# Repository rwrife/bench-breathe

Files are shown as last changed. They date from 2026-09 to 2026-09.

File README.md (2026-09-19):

# Bench Breathe

USB-powered ESP32-C3 workshop air-quality logger that tracks PM2.5 and VOC trends locally to help makers improve ventilation habits without cloud accounts.

## Overview

Bench Breathe is a low-voltage, local-first open-hardware project for hobby workshops and desk labs. It samples particulate and VOC indicators with temperature/humidity context, stores bounded trend history locally, and provides a local companion dashboard for setup, quality states, event notes, and explicit export.

**Bench Breathe is a non-certified advisory trend logger.** It does not determine whether air is safe and is not a medical, emergency, life-safety, or occupational-exposure instrument.

## Intended users and use cases

- Electronics hobbyists comparing trends during soldering or rework.
- 3D-printing users comparing baseline and active-print periods.
- Home workshop users recording manual actions such as opening a window or enabling an independently controlled extractor.
- Makers exporting their own local CSV/JSON data for troubleshooting and analysis.

## MVP workflow

1. Power the device from a reputable 5 V USB SELV source.
2. Connect from a phone/desktop browser on the local network or use USB serial fallback.
3. Complete time-bounded setup and baseline/warm-up prompts.
4. Record a work session and optional ventilation event labels.
5. Review local trends, freshness, quality states, and data gaps.
6. Export or delete local data through an explicit user action.

## Frozen MVP baseline

The normative baseline is in [`hardware/requirements.md`](hardware/requirements.md), with subsystem ownership, dependencies, evidence gates, and the risk register in [`PLAN.md`](PLAN.md).

Key constraints:

- USB 5 V SELV only; <=250 mA steady-state target and <=500 mA peak.
- PM2.5, VOC proxy/index, temperature, and humidity trend channels.
- Default 2 s acquisition, bounded local retention, and deterministic rollover.
- Local HTTP/JSON app interface with USB serial setup/recovery/export fallback.
- Offline sampling without mandatory internet, cloud account, or outbound telemetry.
- Editable KiCad hardware sources and schematic-owned Manufacturer/MPN BOM data.
- Advisory trend language only; static, simulation, bench, and field evidence remain distinct.

## Explicit non-goals and safety limits

- **No mains wiring or control.** No relays, fan switching, actuators, machinery control, or safety interlocks.
- **No hazardous-voltage or USB-PD operation.** The project is nominal 5 V USB SELV only.
- **No medical, emergency, fire/smoke/gas-alarm, life-safety, or occupational-limit function.**
- **No certified accuracy or safe/unsafe determination.** Placement, warm-up, drift, contamination, airflow, and faults can produce misleading data.
- **No mandatory cloud service or internet access.**
- Indoor, dry, non-condensing hobby-workshop use only; not for outdoor, explosive, or industrial-process environments.

Users must follow tool/material manufacturer guidance and appropriate ventilation and PPE practice independently of this device.

## Architecture at a glance

- **Hardware:** USB input/protection/regulation, ESP32-C3, PM/VOC/temp-humidity interfaces, status/input, debug/test access, PCB, and enclosure interface.
- **Firmware:** deterministic acquisition, validity states, bounded retention, atomic configuration, versioned local API, and serial recovery.
- **Companion web app:** setup, status/history, event notes, configuration, explicit export/delete, and accessible advisory messaging.
- **Shared protocol:** [`docs/protocol.md`](docs/protocol.md) is finalized contract v1 (HTTP + USB-serial shapes, units, limits, errors, authorization). The firmware baseline still streams the v0-compatible serial line; adoption is tracked in `docs/release-checklist.md` (T-1).

The device remains authoritative for sensor state, timestamps, configuration limits, and retained records. The app presents that contract and must not turn null/invalid values into apparently valid measurements. For the MVP, compiled app assets are served by the device for offline same-origin use. A physical, time-bounded setup action issues the per-device local credential; this reduces casual LAN access but does not make cleartext HTTP confidential or safe for internet exposure.

## Source tree

- `hardware/requirements.md` — normative MVP requirements and safety boundaries
- `hardware/kicad/bench-breathe.kicad_pro` — editable KiCad project container
- `hardware/kicad/bench-breathe.kicad_sch` — editable A0 electrical schematic and schematic-owned BOM-property source
- `hardware/kicad/bench-breathe.kicad_pcb` — planned editable PCB
- `hardware/component-selection.md` — exact M2 parts, manufacturer-datasheet checks, static power budget, and dated availability snapshot
- `firmware/` — device firmware and verification
- `app/` — local companion web app
- `docs/protocol.md` — device/app contract (v1)
- `docs/bring-up.md` — integration bring-up procedure, wiring/pinouts, calibration, troubleshooting matrix, and evidence ledger
- `docs/release-checklist.md` — fabrication/release artifact gates and open tracked items
- `bom/bom.csv` — generated stuffed-BOM export from schematic properties (regenerate with `python3 bom/export_bom.py`, gate with `python3 bom/verify_bom.py`)
- `bom/README.md` — BOM workflow, sourcing/pricing policy, and file roles
- `bom/non-schematic-items.csv` — enclosure, cables, fasteners, adapter, power supply, and PCB fab with explicit planning status

The current `bom/preliminary-bom.csv` is the issue-#2 planning list reconciled against the schematic (`Schematic_Refs`/`Reconciliation` columns). It is not a fabrication-ready BOM; `bom/bom.csv` is the export artifact.

## Project status

| Milestone | Status |
|---|---|
| M1 — Requirements, architecture, safety, and risk baseline | Baseline documented |
| M2 — Datasheet-backed component selection | Static selection complete; physical validation not started |
| M3 — Editable KiCad schematic and ERC | Complete: clean KiCad 9 ERC plus static validation and PDF review export |
| M4 — Schematic-source BOM export | Complete: `bom/bom.csv` generated from schematic properties with reproducibility + no-fabricated-price gate (`bom/verify_bom.py`) |
| M5 — PCB layout and DRC | A0 evidence board complete: 0 DRC violations with 15 documented unrouted stubs — **not fab release** (see `hardware/pcb-notes.md` §Residuals and `docs/release-checklist.md`) |
| M6 — Firmware baseline | Baseline implemented + natively verified (19 unit tests, pinned device build). Bench flash/flash-recovery and power gating on hardware not performed |
| M7 — Companion app baseline | App MVP + contract v1 complete; 13/13 contract tests against the dev simulator only — never run against a real device |
| M8 — Integration and bench bring-up | Bring-up procedure, wiring/pinouts, and troubleshooting published (`docs/bring-up.md`); all bench steps unexecuted — no prototype exists |
| M9 — Mature fabrication/release bundle | Gate checklist published (`docs/release-checklist.md`); fab artifacts blocked on A1 stub closure |

The editable A0 schematic and its static ERC/analyzer evidence are complete,
as is the A0 evidence PCB (0 DRC violations, 15 documented unrouted stubs —
not fab release), the natively verified firmware baseline, and the
contract-tested companion app (simulator-evidence only). PCB fab export,
simulation, firmware/app builds on hardware, assembly, bench measurement,
field results, and certification are not claimed. See
`docs/bring-up.md` (bench procedure and evidence ledger) and
`docs/release-checklist.md` (release gates and open tracked items).

## Development start

```bash
git clone https://github.com/rwrife/bench-breathe.git
cd bench-breathe
```

Review `hardware/requirements.md`, `PLAN.md`, and the issue backlog before implementing a subsystem. Work should proceed in dependency order and attach the evidence named by the relevant milestone; documentation alone does not satisfy a hardware or physical-test gate.

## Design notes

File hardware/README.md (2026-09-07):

# Hardware Overview

## System block description
Bench Breathe hardware is a USB-powered sensing node with:
- ESP32-C3 controller module
- PM sensor interface (UART/I2C depending on selected module)
- VOC sensor interface (I2C)
- Temperature/humidity sensor interface (I2C)
- User input/status (button + non-color-only indicator)
- USB-C power/data path and programming/debug header

## Selected component baseline

Issue #2 selected exact datasheet-backed parts for the first schematic pass:

- Espressif `ESP32-C3-WROOM-02-N4` controller module
- Sensirion `SPS30` particulate module
- Sensirion `SGP40-D-R4` VOC sensor
- Sensirion `SHT40-AD1B-R2` temperature/humidity sensor
- TI `TPS62162DSGR` 3.3 V buck and `TPS22919DCKR` PM-rail load switch
- GCT `USB4105-GF-A`, TI `TPD4E05U06DQAR`, Bourns `MF-MSMF050-2`, and Diodes Incorporated `SMBJ5.0A-13-F` for the USB input/protection baseline

See [`component-selection.md`](component-selection.md) for pin/electrical/package checks, direct manufacturer documents, the static current budget, sourcing snapshot, and open blockers. Selection does not imply a completed circuit or physical validation.

## Interfaces
- I2C bus for VOC + temp/humidity sensors
- UART or I2C (module-dependent) for PM sensor
- USB serial for bring-up, diagnostics, and fallback data access
- Local network endpoint for companion dashboard

## Power plan
- Input: USB 5V SELV only
- Local regulation and filtering sized for sensor peak current
- Brownout-safe startup and reset behavior required

## Enclosure and assembly concept
- Small desk/workbench enclosure with airflow channels
- Sensor placement strategy that balances intake exposure and heat isolation
- Fastener-based assembly for repairability and sensor replacement

## Safety limits
- No mains/high-voltage circuitry
- No relay or actuator control in MVP
- Advisory trend monitor only; not a certified safety instrument

## Expected KiCad deliverables
- Editable KiCad project: `.kicad_pro`, `.kicad_sch`, `.kicad_pcb` (when PCB begins)
- ERC and DRC outputs with documented exceptions
- Source-of-truth schematic properties for Manufacturer/MPN BOM fields

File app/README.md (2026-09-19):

# Companion App (Local Web) — MVP

A zero-dependency, no-build-step web app that talks to a Bench Breathe
device over the versioned local protocol in [`docs/protocol.md`](../docs/protocol.md)
(contract v1). The compiled assets (`public/`) are plain static files: a real
device serves them itself, so setup and normal use need no internet-hosted
assets and no separately installed server (COM-05).

## Run locally (dev)

Requires Node.js ≥ 20 (nothing else — no `npm install`).

```sh
cd app
npm run dev        # starts the dev stub device on http://127.0.0.1:8123
# open http://127.0.0.1:8123 in a browser
```

The stub simulates a device (sensor physics, history ring, pairing) so the
whole app flow is exercised without a board. It is a **simulator**, not
firmware — real devices serve the same API once Wi-Fi provisioning lands.

First-run pairing demo:

1. In the app, enter device URL `http://127.0.0.1:8123` → **Check device**.
2. Simulate the physical button hold (stand-in for the real button + serial
   code printout): `curl -X POST http://127.0.0.1:8123/__dev/button`
   — prints the pairing code (real devices print it on the USB serial
   console, valid ≤10 min).
3. Enter the code → **Pair**. Live view, history, exports, and settings
   unlock.

## Tests

```sh
cd app
npm test           # node --test test/contract.test.mjs — 13 contract tests
```

`test/contract.test.mjs` asserts the wire shapes, limits, error codes, and
auth rules of `docs/protocol.md` v1 against the stub. It is the cross-project
contract test required by COM-04: when the device's real HTTP server exists,
the same suite runs against it unchanged.

## What the MVP covers

- **Setup flow**: device URL entry, health probe, button-armed pairing with
  single-use code, token storage, Forget-device recovery (COM-06/COM-07 UI).
- **Live view**: per-channel values with explicit data-quality states
  (`ready`/`warming`/`fault`/`unknown`, null + reason), device mode/power
  source/clock quality/uptime/storage, live PM2.5 trend chart.
- **History**: retained-window or wall-clock-range view with null-density
  summary; ordering falls back to `seq` while the device clock is unset.
- **Event tagging**: `session_start` / `window_open` / `fan_on` / custom.
- **Export**: CSV and JSON download via the device's export endpoints
  (`Content-Disposition: attachment`), never automatic.
- **Settings**: sampling-interval and label editing with reject-don't-clamp
  validation feedback (SNS-03), one-click clock sync (quality becomes
  `estimated`, honestly labelled).

## Data ownership & privacy

- The user owns all captured data. No cloud, no telemetry, no analytics.
- Device URL + API token live only in this browser's `localStorage`;
  **Forget device** clears them. History lives on the device until the user
  exports it.
- MVP traffic is plain HTTP on your trusted LAN — **not** confidential
  against a LAN attacker (COM-09). Never port-forward or internet-expose
  the device; the app never describes the device as internet-safe.

## Protocol boundary

- The app is a client of `docs/protocol.md` — no hidden device endpoints,
  no cloud-only paths. All API requests are same-origin (wildcard CORS is
  prohibited and contract-tested).
- Schema changes require an explicit protocol version bump and migration
  notes in `docs/protocol.md`.

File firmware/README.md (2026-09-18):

# Firmware — ESP32-C3 baseline

Bench Breathe firmware for the A0 hardware (`../hardware/kicad/bench-breathe.kicad_sch`):
ESP32-C3-WROOM-02-N4 + SPS30 (UART/SHDLC) + SGP40 + SHT40 (I2C), USB-C powered,
SELV/USB-only — no mains, no actuator control, advisory trend logging only.

Status: **baseline implemented and verified statically + natively (simulation).
Bench verification on a named prototype has NOT been performed** — no target
board existed on the verification host at implementation time (see
"Verification record" and the open bench items below).

## Layout

- `src/core/` — portable C++ core: no Arduino/ESP includes. CRC codecs,
  datasheet command layers (SHT40/SGP40/SPS30), sampler loop, bounded history,
  event log, button FSM, config validation, USB source-state gating (PWR-03
  matrix), NDJSON health renderer. All unit-testable natively.
- `src/device_hal.h` — thin Arduino/Wire/UART implementations (device env only).
- `src/main.cpp` — device glue: pin map, power gate, tick loop, serial stream.
- `test/test_core/` — datasheet-vector codec tests (SHT4x v6.4 §4.4/§4.6,
  SGP40 v1.2 Tables 9–10, SPS30 v2.0 §5.2/§5.3 example frames).
- `test/test_behavior/` — sampler/power-gate/button/config behavior over
  fake buses (`src/hal/host_sim.h`).

## Pinned toolchain (reproducible build)

Verified with PlatformIO Core 6.1.18 on Linux x86-64, 2026-09-18:

| Pin | Value |
|---|---|
| `platform` | `espressif32@6.10.0` (pinned in `platformio.ini`) |
| Arduino core | 3.20017.241212 (Arduino ESP32 core 2.0.17, installed by the platform pin) |
| `test platform` | `native@1.2.1` |
| C++ standard | `-std=gnu++17` with `build_unflags = -std=gnu++11` (core 2.x default is gnu++11 — the unflag is required) |

Install: `pip install platformio` then from `firmware/`:

```sh
pio test -e native     # host unit tests (19 test cases)
pio run -e esp32c3     # device build (clean rebuild: pio run -e esp32c3 -t clean first)
```

This is the "documented local automation" build path required by the issue;
the repo has no CI workflows, so these commands are the reproducible gate.
Any toolchain pin bump requires re-running BOTH commands and refreshing the
record below.

## Verification record (actual output, 2026-09-18, PlatformIO Core 6.1.18)

`pio test -e native`:

```
================= 19 test cases: 19 succeeded in 00:00:00.757 =================
```

`pio run -e esp32c3` (after `-t clean`):

```
RAM:   [====      ]  40.8% (used 133692 bytes from 327680 bytes)
Flash: [==        ]  22.1% (used 290162 bytes from 1310720 bytes)
========================= [SUCCESS] Took 2.35 seconds =========================
```

Evidence classes (per `hardware/requirements.md` §10): codec vectors and
behavior tests are **simulation-class** (host execution of the real code
paths against datasheet vectors/fake buses); the device build is
**static-class** (compiles + links, fits memory). Neither is a bench claim.

## Flashing, recovery, and update path

Hardware: J1 USB-C into the module's native USB (D+/D- via series R11/R12),
plus J3 debug header carrying 3V3/GND/EN/BOOT(GPIO9)/U0TXD/U0RXD.

**Flash (normal):**
```sh
pio run -e esp32c3 -t upload        # esptool via PlatformIO; uses USB CDC
# or explicitly:
pio run -e esp32c3 -t upload --upload-port /dev/ttyACM0
```

**Download-mode recovery** (firmware bricked / boot loop): pull BOOT (J3
pin 4, net `BOOT_GPIO9`) low while pulsing EN (J3 pin 3) or power-cycling;
the ESP32-C3 ROM bootloader enumerates and `pio run -t upload` works again.
R10 keeps GPIO9 high at normal boot; the header is the manual entry point.

**Full re-flash from scratch (recovery escalation):**
```sh
pio run -t erase                    # blank flash (erases history + config)
pio run -e esp32c3 -t upload
```

**Update/rollback path:** releases are tagged `firmware-vX.Y.Z`; updating is
`git checkout firmware-vX.Y.Z && pio run -e esp32c3 -t upload`. Rollback is
the same command on the previous tag (config schema `Config.schema` is
versioned; incompatible schema values fail `validate_config` and fall back
to defaults rather than reading old-layout garbage). OTA over Wi-Fi is
deliberately NOT in the baseline (issue #7 protocol scope).

> Bench status: none of the three commands above has been executed against a
> physical board yet — no target was attached to the verification host. This
> remains an open acceptance item tracked in issue #8's bring-up checklist.

## What the baseline does

1. **Power gating (PWR-03):** classifies the USB source from CC1/CC2 ADC
   windows (`core/power_source.h`) + CDC enumeration + REG_PG; the PM rail
   enable (U7, GPIO6) and Wi-Fi stay off outside full-sensing mode; repeated
   brownout reboots pin the device to recovery mode.
2. **Acquisition (SNS-02/03/04):** config-bounded interval (2–60 s, invalid
   values rejected not clamped); per tick: SHT40 → SGP40 (humidity-
   compensated, datasheet default words when SHT40 faults) → SPS30 poll.
   Slower channels repeat latest value with retained age; unavailable values
   are explicit nulls with reasons; warm-up windows follow datasheets
   (SPS30 30 s, SGP40 1 h baseline conditioning).
3. **Storage (DAT-01..03):** 24-byte compact records, deterministic
   oldest-first rollover, 5-min aggregate folding (mean-over-valid / max-VOC),
   capacity/used/oldest/newest published in health output. Wall-clock base
   freezes on first sync so corrections never reorder records (SNS-06).
   **Capacity caveat:** DAT-01/02 full windows (43,200 raw / 8,640 agg,
   ~1.04 MB + 0.28 MB) exceed SRAM and need the mmap'd flash partition —
   the baseline runs a 4096-record (~2.3 h @ 2 s) RAM arena and publishes
   honest capacity in the health stream.
4. **Serial fallback (COM-03):** 1 Hz NDJSON health line over USB CDC with
   protocol version, mode, source, storage state, clock quality, and all
   four channels with status+unit+value-or-null.
5. **Button (COM-06/DAT-06 detection):** debounced edge-to-edge hold windows —
   short press, ≥5 s setup-hold, ≥15 s factory-hold (fire on release only).
   Actions are event-marked; the setup/pairing flow itself is issue #7.

## Open bench-gated items (do not confuse with the above evidence)

- Flash/recovery/update commands untested on hardware (no board on host).
- CC advertisement ADC calibration vs the R1/R2 divider + ESP32-C3 ADC
  accuracy (windows are spec-conservative; bench must confirm boundaries).
- SHT40 thermal placement/slow-cadence accuracy, SGP40 baseline quality,
  SPS30 fan-start current overlap with Wi-Fi TX — all need PWR-04 captures.
- Full DAT-01/DAT-02 capacity via mmap flash partition; DAT-04/05/06
  power-loss-atomic persistence needs the flash store + fault injection.
- Wi-Fi/HTTP API, pairing, auth, setup-mode expiry (COM-04..09): issue #7.

## Responsibilities / interfaces (inherited plan)

Initialize sensors and validate readiness states; deterministic sampling +
timestamped records; bounded retention; local protocol endpoints (issue #7);
calibration/baseline workflows surfaced as channel status; button events and
indicator states. Provisioning/update: serial first, versioned config schema,
documented flash/rollback above.

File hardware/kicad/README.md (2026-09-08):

# KiCad hardware sources

`bench-breathe.kicad_sch` is the editable A0 electrical schematic. It stores exact Manufacturer/MPN/LCSC/Datasheet/Package/BOM Comments fields and implements USB power/data/CC sensing, the fixed 3.3 V regulator, controller, sensors, programming/debug, local status/button, and named test points.

Project-local functional symbols and the SGP40 land pattern live under `lib/`; `generate_schematic.py` regenerates the editable source, and `validate_schematic.py` checks critical datasheet pin maps, net assignments, BOM properties, ERC JSON, and the PDF export.

Reproduce the static evidence from the repository root:

```bash
python3 -m venv /tmp/bench-breathe-ksa-env
/tmp/bench-breathe-ksa-env/bin/pip install -r hardware/kicad/requirements.txt
KICAD_SYMBOL_DIR=/usr/share/kicad/symbols /tmp/bench-breathe-ksa-env/bin/python hardware/kicad/generate_schematic.py
kicad-cli sch erc hardware/kicad/bench-breathe.kicad_sch --format json --output hardware/kicad/reports/erc.json --exit-code-violations
kicad-cli sch export pdf hardware/kicad/bench-breathe.kicad_sch --output hardware/kicad/exports/bench-breathe-schematic.pdf
KICAD_SYMBOL_DIR=/usr/share/kicad/symbols /tmp/bench-breathe-ksa-env/bin/python hardware/kicad/validate_schematic.py --erc hardware/kicad/reports/erc.json --footprint-dir /usr/share/kicad/footprints
```

The zero-violation ERC and validator are **static schematic evidence only**. They do not prove PCB routing, signal integrity, radio performance, power transients, assembly, sensor accuracy, or physical operation.

Re-run the metadata gate from the repository root with:

```bash
python3 hardware/scripts/verify_component_selection.py
```

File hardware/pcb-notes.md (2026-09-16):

# Bench Breathe A0 PCB notes

**Evidence class:** static layout + DRC + autoroute log. No bench, radio,
thermal, or field measurements were performed. The board is A0
first-silicon intent; all claims below are geometry and design-rule facts
reproducible from the committed sources.

## Inputs and reproduction

Electrical truth comes only from the A0 schematic netlist
(`bench-breathe.kicad_sch`, regenerated by `generate_schematic.py`) — pin
maps are never re-typed here. From the repository root:

```bash
kicad-cli sch export netlist hardware/kicad/bench-breathe.kicad_sch -o /tmp/bb-netlist.net
python3 hardware/kicad/scripts/netlist_json.py /tmp/bb-netlist.net /tmp/bb-netlist.json
# pcbnew API build (inside the KiCad 9 image used by the kicad-cli shim):
docker run --rm -u $(id -u):$(id -g) -e HOME=/tmp/kicad-home \
  -v "$PWD":/hw -v /tmp:/tmp parts-tally-kicad:9-arm64 \
  sh -c 'mkdir -p $HOME/.config/kicad/9.0; cp /usr/share/kicad/template/fp-lib-table $HOME/.config/kicad/9.0/; \
  python3 /hw/hardware/kicad/scripts/build_pcb.py /tmp/bb-netlist.json /hw/hardware/kicad/bench-breathe.kicad_pcb'
# Specctra route loop (FreeRouter 2.1.0 on JDK 21, headless; each pass
# re-exports the DSN from the just-imported board):
#   scripts/export_dsn.py board.kicad_pcb passN.dsn
#   java -Djava.awt.headless=true -jar freerouting-2.1.0.jar -de passN.dsn -do passN.ses -mp 20 -gui.enabled=false
#   scripts/import_ses.py board.kicad_pcb passN.ses
#   scripts/refill_zones.py board.kicad_pcb        # stored fill is stale after import
#   scripts/stitch_pour_islands.py board.kicad_pcb # GND pour islands -> stitching vias (bounded, idempotent)
#   scripts/fix_starved_pads.py board.kicad_pcb REF:PAD ...
#   scripts/close_stubs.py board.kicad_pcb passN-drc.json
kicad-cli pcb drc hardware/kicad/bench-breathe.kicad_pcb --severity-error --severity-warning \
  --format json --output hardware/kicad/reports/pcb-drc-final.json
```

`hardware/kicad/bench-breathe.kicad_pro` carries the real design rules and
net classes (KiCad 9 reads DRC constraints from the project file, not from
API-side board settings): default 0.2 mm clearance/track, Power class 0.4 mm
(VBUS, VBUS_FUSED, SW_NODE, PM_5V, +3V3), USB class 0.25 mm between the
connector and the module. See `scripts/make_project_settings.py` for the
rationale of the 0.2 mm min through-drill (manufacturer ESP32 module
heat-sink vias and WSON thermal-via land pattern ship 0.2 mm drills).

## Board concept (KiCad coordinates, +Y toward the bottom edge)

65 × 75 mm, two copper layers, four M3 corner holes at (±3.5) insets.
Functional zones:

- **USB entry / protection (bottom edge):** J1 USB-C (top-mounted
  horizontal, opening facing the y=75 edge, two press-fit anchoring slots
  with copper-free rings), TPD4E05 ESD array U6 at the escape, CC1/CC2 5.1 kΩ
  Rd resistors, PPTC F1 + SMBJ5.0A TVS D1 on VBUS, then 0 Ω DM/DP config
  links (R11/R12).
- **3.3 V buck (bottom-left):** TPS62162 U5 with input bulk C1, 2.2 µH L1
  and 22 µF C2 in a tight power loop; PG pull-up R3 beside it.
- **PM rail (bottom-right):** TPS22919 load switch U7 + bulk C10 feeding the
  JST PH SPS30 harness header J2 at the right edge (53.5, 50).
- **Controller (top-center):** ESP32-C3-WROOM-02 U1 at (32.5, 20.5) with the
  antenna arm oriented toward the **top edge** and its copper-free keepout
  rule area (18.25–46.75 × 2.15–13.65 mm, both layers, priority 1) fully
  inside the board outline; EN/BOOT/3V3 passives at its corners; 1×06 debug
  header J3 flat on the left side (14.4, 30).
- **Sensors (right-center):** SGP40 U3 + SHT40 U4 with local bypass parts on
  a quiet island away from the buck loop; I2C pull-ups R5/R6 sit between
  master and slaves. SHT40's open cavity (NoCentralPad footprint) keeps the
  sensing opening free of paste/fill.
- **User interface (left/right middle):** button SW1 + pull-up/debounce at
  x=7.5 (reachable from a desk front-left) and status LED D2 + R9 at the
  right middle, away from the sensor island so hand heat does not bias SHT40.

## Grounding strategy (AC-3)

Solid GND pour on **both** layers (verified filled: F.Cu ≈ 3.14 × 10³ mm²,
B.Cu ≈ 3.70 × 10³ mm² after the final post-route refill), thermal relief to
pads, with full connect set on the edge/shell pads that starve thermal relief (J1 A12/B1,
U6 pad 8, J3 pad 2, U3 EP). Rationale:

- Two solid layers give every signal a same-or-adjacent-layer return; the
  buck input loop (C1→U5→L1→C2) is kept small at the bottom-left corner so
  its di/dt does not ride the sensor return.
- The SGP40/SHT40 island routes I2C and VDD over unbroken pour; sensor VDD
  uses the datasheet RC (10 Ω + 100 nF). The A0 plan is one ground domain —
  separation is by layout, not by a split plane.
- SPS30 UART runs from the module to the right-edge J2 over the pour. The
  SPS30 housing is chassis-tied internally per Sensirion, so J2 carries no
  separate chassis path.
- USB DM/DP run short through the ESD array and 0 Ω links without layer
  transitions where the router allowed.

## Keepouts and documented exceptions (AC-4)

- **Antenna keepout:** priority-1 rule area over the module antenna arm
  forbids copper pour on both layers; `SetDoNotAllow*` flags allow the
  module's own pads/vias inside the rectangle. The keepout is inside the
  board outline; the top-edge clearance is what matters for radio coupling.
- **Mounting-hole (r=2.7 mm) and USB press-fit-tab copper-free rings** are
  priority-1 rule areas that carve the pour but explicitly allow their own
  hole/tabs (default rule areas would flag the hole's own pad).
- **SHT40 cavity:** project footprint has no central pad and no paste; the
  validator asserts the footprint choice at schematic level.

## Testability and fab-readiness notes (AC-5)

- 19 named test points, one pad each: TP1 VBUS, TP2 VBUS_FUSED, TP3 +3V3,
  TP4 GND, TP5 PM_5V, TP6 REG_PG, TP7 EN, TP8 BOOT_GPIO9, TP9 I2C_SDA,
  TP10 I2C_SCL, TP11 USB_DP, TP12 USB_DM, TP13 CC1_SENSE, TP14 CC2_SENSE,
  TP15 PM_ENABLE, TP16 USER_BUTTON_N, TP17 PM_UART_RX, TP18 PM_UART_TX,
  TP19 SGP_VDD. TP11/TP12 sit on the module side of the 0 Ω links so the
  host-side pair can be isolated at the bench.
- Mounting: 4 × M3 at (3.5, 3.5) … (61.5, 71.5) with copper-free rings;
  J1 press-fit tabs are anchored by two plated slots plus soldered shell
  pads.
- Connector orientation: J1 opening faces the bottom edge; J2 (SPS30
  harness) exits the right edge; J3 debug header is horizontal on the left
  so a ribbon/Tag-Connect exits sideways.
- Polarity marks: all polarized parts (D1, D2, C1–C3, C10, U5, U7, J1, J2)
  keep silkscreen polarity graphics; TP/SW references stay visible (shrunk
  0.8 mm/0.15 mm stroke text) because test-point identity is part of the
  testability criteria. Dense R/C/D references are hidden post-route —
  values and courtyards remain on Fab layers.

## Residuals carried into A1 / issue #8 (AC-4 honesty)

**Final DRC state** (`reports/pcb-drc-final.json`, KiCad 9.0.9, severities
error+warning, evidence class = static geometry check): **0 violations**;
17 `unconnected_items`, of which 2 are `Zone [/GND] <-> Zone [/GND]` pairs
anchored at the pour outline's (0.3, 0.3) corner — pseudo-ratsnest artifacts
of the filled polygon, not routable copper — leaving **15 open ratsnest
edges** as the explicit pre-fab blocker. Per-pair collision dumps for every
one of the 15 are in `reports/ratsnest-diagnosis-final.txt`. Deterministic
closure attempts (`close_stubs.py`, straight + both L topologies, 0.2 mm
clearance capsule + keepout collision): `fixed=0 left=15 skipped=2` — every
remaining pair is fenced by foreign copper at exactly netclass clearance
(pitfall-30 physics gate, not router failure). FreeRouter itself exited
naturally at plateau pass #999 (15 unrouted — same 15 edges;
`reports/freerouter-pass5-summary.txt`).

Blocker classes for A1, each with its named fix (15 = 6 + 3 + 3 + 3):

- **USB-C/TPD4E05 fanout congestion (CC1_SENSE ×1, CC2_SENSE ×3,
  VBUS ×2):** the TPD4E05 DFN-10 escape and the
  USB-C mid-mount pads leave corridors narrower than track+2×clearance in
  the 0.25 mm USB class; J1 B4↔B9 VBUS bonding and the CC lines cross the
  A5/A6/B5/B6 pad rows. Fix: local `scan_fanout` netclass (0.13 mm/0.13
  mm) for CC*/VBUS-bond segments plus a 0.35 mm pad-pair nudge of
  U6, or fan the CC sense lines out on B.Cu immediately under U6.
- **SHT40 cavity keepout corridor (I2C_SDA ×1, I2C_SCL ×1, +3V3 ×1,
  all landing on U4):** straight closures pass the pure-collision check
  but cross the SHT4x sensing-cavity `tracks not_allowed` rule area. Fix:
  route the last hop inside the footprint-embedded fanout corridors the
  datasheet allows, or re-anchor the cavity keepout polygon with the
  pad-pair gaps open.
- **Module-row edge stubs (I2C_SCL to TP10 ×1, REG_PG to U1.15 ×1,
  USER_BUTTON_N to U1.10 ×1):** the 26.37 mm +3V3 bus rail and the
  module's own USB_DM/BOOT pads sit at exactly clearance. Fix: move the
  bus rail one grid notch (0.25 mm) east at re-place and re-anchor TP9/
  TP10 outside the pad-row shadow.
- **Buck/power-loop congestion (SW_NODE ×1, VBUS_FUSED ×2):** the 0.4 mm
  Power class cannot thread the WSON-8 pad row or the R12/C12/U7 escape.
  Fix: Power-class width exception (0.2 mm for the last 1 mm) or nudge
  L1/TP2 so their stubs leave the pad shadow; re-place TP2 beside the F1
  output stub.

Until these 15 close (A1 nudge or manual fanout), **the board is NOT fab
release** — it is an A0 evidence board for placement/DRC/geometry
validation only.
- USB DM/DP are not length-tuned or impedance-controlled (≈ 0.25 mm/0.2 mm
  on generic 1.6 mm 2-layer ≈ 95–110 Ω uncontrolled), acceptable for the
  ESP32-C3 full-speed (12 Mbps) USB used for bring-up and the companion
  app. **No USB High-Speed or compliance claim is made.**
- Antenna coupling, radio range, and RF certification are bench/field
  evidence (issue #8); static checks cannot evaluate them.

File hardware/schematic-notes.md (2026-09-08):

# Bench Breathe A0 schematic notes

## Scope and safety boundary

This is a **static schematic capture** for a nominal 5 V USB SELV, non-certified advisory trend logger. It contains no mains, relays, actuators, USB-PD controller, or hazardous-voltage interface. ERC and analyzer results do not prove PCB layout, assembly, radio performance, sensor accuracy, power transients, or physical operation.

## Datasheet-backed interfaces

- **J1 / U1 native USB:** USB4105 receptacle A6/B6 and A7/B7 are joined as `USB_CONN_DP`/`USB_CONN_DM`, protected by TPD4E05U06, then pass through 0 Ω configuration links to `USB_DP`/`USB_DM` at ESP32-C3-WROOM-02 pins 14/13. The 0 Ω values follow Espressif Figure 9-1 and preserve a layout/bench tuning point; the analyzer's generic 22 Ω suggestion is not substituted for the module-vendor reference circuit. USB routing and ESD placement remain issue #5 layout work.
- **USB-C source advertisement:** CC1 and CC2 each have 5.1 kΩ Rd to GND and also reach ADC-capable ESP32 GPIO0/GPIO1 as `CC1_SENSE`/`CC2_SENSE`. Firmware must distinguish default, 1.5 A, and 3 A advertisement voltages and separately honor USB configuration/suspend states. The schematic does not claim that firmware behavior or current limits have been bench-tested.
- **3.3 V regulator:** TPS62162 fixed 3.3 V uses 10 µF input, 2.2 µH output inductor, 22 µF output capacitor, 100 kΩ PG pull-up, FB-to-GND, VOS-to-3V3, and exposed-pad/AGND/PGND ground connections from TI tables 2–4 and pin table 6.
- **ESP32-C3 module:** 3.3 V has local 10 µF + 100 nF. EN has 10 kΩ/1 µF delay per Espressif Figure 9-1. GPIO9 is pulled up for normal boot and exposed with EN/UART on the 3.3 V-only debug header.
- **SPS30:** TPS22919 defaults the PM 5 V rail off via its internal ON pulldown. QOD is tied to VOUT for discharge. J2/U2 pin order is VDD, RX, TX, SEL, GND; SEL is left floating to select UART, which Sensirion recommends for cables longer than 20 cm. UART avoids back-powering an unpowered SPS30 from the always-pulled-up sensor I²C bus. ESP32 UART0 is shared with the optional debug header, so an external UART adapter must not drive it while SPS30 is active. Native USB remains the normal recovery/serial path. The SPS30 housing is internally tied to signal GND and must not gain an independent chassis-current path.
- **SGP40:** project symbol follows Sensirion Table 6. VDD uses 10 Ω + 100 nF RC decoupling, VDDH uses 1 µF, and pin 4 plus exposed pad are grounded. The project footprint follows Sensirion Figure 14 and was cross-checked against KiCad upstream footprint MR 2511.
- **SHT40:** project symbol follows Sensirion Figure 18. The open-cavity package needs airflow, no copper under the sensing cavity, contamination controls, and thermal separation in issue #5.

## GPIO allocation

| ESP32 module pin | GPIO/function | Net / use |
|---|---|---|
| 3 | GPIO4 | `I2C_SDA` |
| 4 | GPIO5 | `I2C_SCL` |
| 5 | GPIO6 | `PM_ENABLE` |
| 6 | GPIO7 | `STATUS_LED_K` |
| 8 | GPIO9 | `BOOT_GPIO9` |
| 10 | GPIO10 | `USER_BUTTON_N` |
| 11 | GPIO20/U0RXD | `PM_UART_TX` (sensor TX to MCU RX) |
| 12 | GPIO21/U0TXD | `PM_UART_RX` (MCU TX to sensor RX) |
| 13 | GPIO18/USB_D- | `USB_DM` |
| 14 | GPIO19/USB_D+ | `USB_DP` |
| 15 | GPIO3 | `REG_PG` |
| 17 | GPIO1/ADC | `CC2_SENSE` |
| 18 | GPIO0/ADC | `CC1_SENSE` |

GPIO2 and GPIO8 are intentionally no-connect on A0. GPIO9 is a boot strap and is externally pulled high.

## Native ERC result

KiCad 9.0.9 `sch erc --format json --exit-code-violations` reports **0 violations** in `hardware/kicad/reports/erc.json`. There are no warning exceptions to justify.

## Analyzer triage and intentional exceptions

- `PP-001` reports that SGP40 U3.1 lacks a DC path because its generic graph rule accepts only series resistors ≤1 Ω. Sensirion Figure 5 explicitly requires an RC element on VDD; A0 uses 10 Ω and 100 nF, which provides a DC path (about 30 mV drop at the documented 3 mA maximum). This finding is a rule-threshold false positive, not an open circuit.
- `UC-001`/`UC-002` look only at J1's pre-fuse `VBUS` net. A0 deliberately places the 10 µF buck input capacitor and SMBJ5.0A TVS on `VBUS_FUSED`, immediately after F1, so a sustained TVS fault is current-limited and the TPS62162 input sees its manufacturer-recommended 10 µF. Placement close to J1/F1 and USB inrush behavior remain PCB/bench gates.
- J2 is an internal keyed SPS30 harness boundary and J3 is an internal 3.3 V debug header. Their lack of dedicated connector ESD is accepted for A0's enclosed dry indoor product boundary; external-access and cable-route assumptions must be rechecked during enclosure/layout review.
- `PU-001` assumes SPS30 SEL must have a pull-down. Sensirion Table 4 explicitly defines SEL floating as UART mode and SEL low as I²C mode; A0 intentionally leaves U2.4 and J2.4 no-connect to select UART.

## Evidence classes

- **Static:** performed — manufacturer PDF pin/application checks, generated editable KiCad source, critical pin/net validator, metadata gate, native ERC, schematic analyzer, and PDF export.
- **Simulation:** not performed in issue #3.
- **PCB/DRC:** not applicable yet; issue #5 owns PCB layout.
- **Bench:** not performed; no assembled prototype exists.
- **Field:** not performed.

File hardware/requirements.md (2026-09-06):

# Bench Breathe MVP Requirements

Status: **baseline for MVP design**

Scope: USB-powered indoor workshop air-quality trend logger

Evidence state: requirements only; no electrical, firmware, app, or physical validation is implied

Requirement IDs are stable references for schematic, firmware, app, and bring-up work. A later design change may revise a requirement through review, but implementations must not silently diverge from this baseline.

## 1. Product intent and boundaries

Bench Breathe helps a user observe particulate, VOC, temperature, and humidity trends around a hobby workbench and compare those trends with manually recorded ventilation events. It is an advisory logger, not a protective control or calibrated exposure instrument.

### In scope for the MVP

- One desk/workbench device powered from USB 5 V SELV.
- PM2.5, VOC-index/proxy, temperature, and relative-humidity trend channels.
- Local acquisition, bounded storage, viewing, event annotation, and explicit export.
- Local-network access with a USB serial fallback for setup, diagnostics, and export.
- Editable KiCad, firmware, protocol, and web-app sources.
- Reproducible static checks and documented bench bring-up before any release claim.

### Explicitly out of scope

- Mains wiring, mains sensing, relay outputs, fan control, or any actuator control.
- USB Power Delivery negotiation or operation above nominal USB 5 V.
- Medical, diagnostic, emergency, life-safety, or occupational-exposure decisions.
- Certified indoor-air-quality, industrial-hygiene, or regulatory-limit measurements.
- Automatic alarms that imply a safe/unsafe determination.
- Cloud accounts, mandatory internet access, remote telemetry, or unattended remote control.
- Outdoor, wet, condensing, explosive, corrosive, or industrial-process environments.

## 2. Electrical requirements

| ID | Requirement | Acceptance evidence |
|---|---|---|
| PWR-01 | The only external power input shall be nominal 5 V USB from a SELV source. No circuit shall intentionally connect to mains or hazardous voltage. | Schematic review and connector inspection |
| PWR-02 | Full sensing is supported only when the device detects a USB-C 1.5 A/3 A CC advertisement or a USB 2.0 host completes configuration for a 500 mA load. The user documentation shall additionally require a safety-certified 5 V source rated at least 1 A; that safety certification is an external user constraint, not something the device claims to detect. | Schematic review, user-document review, and source-state matrix test |
| PWR-03 | The device shall use USB-C sink terminations and shall not negotiate USB-PD. Hardware/firmware shall implement the current ceilings and modes in the source-state matrix below, keep the PM sensor and Wi-Fi disabled outside full-sensing mode, report insufficient power over serial when available, and avoid repeated brownout boot loops. | USB power-state and current test for every matrix row |
| PWR-04 | With a supported source, steady-state average input current target is no more than 250 mA and peak input current shall remain at or below 500 mA, including sensor startup and radio transmit. | Logged average plus oscilloscope/current-probe worst-case capture |
| PWR-05 | USB input protection shall include a documented overcurrent strategy and protection against ESD/transient exposure appropriate to a user-accessible USB connector. | Datasheet-backed schematic review and DRC |
| PWR-06 | USB-C sink configuration and any data connection shall follow the selected connector/controller datasheets; unused high-voltage or PD functions shall not be populated. | Pin-by-pin schematic review against manufacturer datasheets |
| PWR-07 | A power fault or brownout shall not leave partially committed configuration or history records presented as valid. | Firmware fault-injection test |
| PWR-08 | All user-accessible signal connectors shall remain within SELV/logic-level domains and shall have documented pinout, voltage, and current limits. | Schematic and bring-up guide review |

### USB source-state matrix

| Detectable state | Allowed mode | Maximum input current | Pass condition |
|---|---|---:|---|
| USB-C CC advertises 1.5 A or 3 A at 5 V | Full sensing | 500 mA peak | PM and Wi-Fi may start; measured peak remains <=500 mA |
| USB 2.0 host, before configuration | Recovery/serial only | 100 mA | PM and Wi-Fi remain off; device enumerates without brownout |
| USB 2.0 host grants configured 500 mA load | Full sensing | 500 mA peak | PM and Wi-Fi may start; measured peak remains <=500 mA |
| USB suspend | Suspended | 2.5 mA | Sensors and radio are off; measured current is <=2.5 mA |
| Default-current/unknown CC with no successful host configuration, charge-only legacy cable, denied configuration, or detected source droop | Recovery/error only | 100 mA | Full sensing never starts; insufficient-power status is available when serial is functional; no reset loop occurs |

## 3. Sensing requirements

| ID | Requirement | Acceptance evidence |
|---|---|---|
| SNS-01 | The device shall expose PM2.5, VOC index/proxy, temperature, and relative-humidity channels with units and validity state. | Protocol contract tests |
| SNS-02 | The default acquisition tick shall be 2 s. A channel with a slower datasheet-qualified cadence may repeat its latest value but shall retain its own sample age and validity. | Firmware timing test and datasheet review |
| SNS-03 | The configurable acquisition interval shall be bounded to 2–60 s; invalid values shall be rejected rather than silently clamped. | Firmware unit/contract tests |
| SNS-04 | Each channel state shall be one of `ready`, `warming`, `fault`, or `unknown`; unavailable values shall be explicit nulls with a reason. | Protocol contract tests |
| SNS-05 | Sensor warm-up, conditioning, baseline, and compensation behavior shall follow the selected manufacturer datasheets and be surfaced to the user. | Datasheet review and bench bring-up record |
| SNS-06 | Samples shall carry monotonic ordering plus wall-clock time and clock-quality metadata when wall-clock time is available. Clock correction shall not reorder stored samples. | Firmware rollover/time-correction tests |
| SNS-07 | Every MVP surface shall describe readings as trends or sensor proxies. A stronger accuracy, exposure, health, or safe/unsafe claim is prohibited in the MVP and requires a separately reviewed post-MVP requirements and validation program. | Documentation and UI copy review |

## 4. Storage and data ownership

| ID | Requirement | Acceptance evidence |
|---|---|---|
| DAT-01 | The device shall retain at least 24 h of 2 s trend records (43,200 acquisition ticks) under the final record format. | Storage-capacity calculation and rollover test |
| DAT-02 | The device shall retain at least 30 days of 5 min aggregates (8,640 intervals) or an equivalent documented bounded summary. | Storage-capacity calculation and rollover test |
| DAT-03 | Retention shall use deterministic oldest-first rollover and shall publish capacity, used space, oldest timestamp, and newest timestamp. | Firmware storage tests and API contract test |
| DAT-04 | Configuration writes and history metadata updates shall be atomic or recoverable after reset/power loss. | Fault-injection and reboot recovery tests |
| DAT-05 | A `clear history` action shall delete all raw samples, aggregates, and event labels while retaining device configuration. It shall require an authenticated local session plus explicit app confirmation; completion metadata shall be committed atomically so interrupted erasure cannot make deleted records queryable or exportable after reboot. | Firmware/app deletion and power-interruption tests |
| DAT-06 | Factory reset shall remove user configuration, pairing credentials, event labels, raw samples, and aggregates. It shall require a sustained physical-button action; the app may guide but shall not remotely complete the reset. | Firmware/app reset and reboot tests |
| DAT-07 | CSV and JSON export shall occur only after an explicit authenticated local user action and shall include schema/protocol version, units, channel validity, and clock-quality metadata. | Export fixture and authorization tests |
| DAT-08 | No microphone, camera, location, contact, or cloud-account data shall be requested or stored by the MVP. | App permission/static review |
| DAT-09 | Event labels are user-controlled local text; implementations shall define a bounded length and escape them safely in UI and exports. | App/firmware input-boundary tests |

## 5. Connectivity and protocol requirements

| ID | Requirement | Acceptance evidence |
|---|---|---|
| COM-01 | Normal operation shall not require internet access. Loss of LAN access shall not stop sampling or retention. | Offline integration test |
| COM-02 | The primary app transport shall be versioned HTTP/JSON on the local network. | Protocol contract tests |
| COM-03 | USB serial shall provide a documented fallback for setup, health/status, configuration recovery, and data export. | Serial integration test |
| COM-04 | Before firmware/app integration, the current `docs/protocol.md` Draft v0 shall be finalized as the single versioned contract for HTTP and serial data shapes, units, limits, errors, authorization, and compatibility. Breaking changes require a new major API version or documented migration. | Protocol issue acceptance plus cross-project contract tests |
| COM-05 | The compiled companion app shall be served by the device so setup and normal use require no internet-hosted assets or separately installed server. API requests shall be same-origin; wildcard CORS is prohibited. | Offline browser test and firmware/app build inspection |
| COM-06 | Setup mode shall begin only after a physical-button action, be visibly indicated, expire within 10 min, and exit after successful pairing/provisioning. Factory reset returns the device to unprovisioned state but shall not start setup mode until another physical-button action. | Firmware/app setup, timeout, and reset integration tests |
| COM-07 | Static app assets and a minimal non-sensitive health response may be fetched without authentication. After a sustained physical-button action, USB serial shall reveal a single-use pairing code with at least 128 bits of cryptographically secure random entropy for at most 10 min. During that window only, an unauthenticated same-origin pairing endpoint may exchange the code for the per-device API credential; the first successful exchange consumes the code and closes the endpoint. Factory reset replaces all pairing material. Every other API resource requires the credential; state-changing requests also use same-origin request protections, and USB-serial mutation commands require a separate recent physical-button confirmation. | Entropy/source review plus bootstrap race, authorization, cross-origin, expiry, reset, and serial-mutation tests |
| COM-08 | The device shall not create outbound cloud connections in the MVP. Network listeners shall be limited to documented local services. | Firmware static review and network capture |
| COM-09 | MVP HTTP traffic is not confidential against an attacker already on the trusted private LAN. This residual risk and the prohibition on internet exposure/port forwarding shall be visible in setup documentation; the UI shall not describe the device as internet-safe. | Threat-model/documentation review and network capture |

## 6. User interface and accessibility requirements

| ID | Requirement | Acceptance evidence |
|---|---|---|
| UX-01 | Device state shall not be communicated by color alone; the app shall provide textual state and the device shall provide a documented non-color-only pattern or behavior. | UI review and bring-up test |
| UX-02 | The app shall distinguish sensor warming/fault/unknown states from healthy measurements and shall not graph invalid null values as zero. | App tests |
| UX-03 | Trend displays shall show units, time range, freshness, and data gaps. | App tests and manual accessibility review |
| UX-04 | Destructive reset/delete actions and configuration changes shall require explicit confirmation and report partial failure. | App integration tests |
| UX-05 | Advisory copy shall avoid safe/unsafe, healthy/unhealthy, medical, emergency, or certified-exposure claims. | Documentation/UI copy review |

## 7. Mechanical and environmental requirements

| ID | Requirement | Acceptance evidence |
|---|---|---|
| MEC-01 | The assembled enclosure target shall not exceed 120 mm × 120 mm × 80 mm. | CAD/enclosure measurement |
| MEC-02 | The enclosure shall open non-destructively and permit sensor/PCB replacement using ordinary hand tools. | Assembly trial |
| MEC-03 | USB cable strain relief and board mounting shall prevent connector load from being carried only by solder joints. | Mechanical inspection |
| MEC-04 | Airflow openings shall expose the sensing path while discouraging direct touch, debris entry, and recirculation of MCU/regulator heat. | Enclosure review and thermal/response comparison |
| ENV-01 | MVP use is indoor, dry, non-condensing operation only. Design target is 10–35 °C and 20–80% RH, bounded further by the selected component datasheets. | Datasheet audit and chamber/controlled-environment check if available |
| ENV-02 | Outdoor/weather exposure, condensation, solvent-rich atmospheres, and explosive dust/gas environments are prohibited. | Product labeling/documentation review |

## 8. Cost, serviceability, and source requirements

| ID | Requirement | Acceptance evidence |
|---|---|---|
| CST-01 | Prototype BOM target is USD 35–60 and ceiling is USD 75, excluding host device, tools, shipping, tax, and optional debug accessories. | Dated BOM sourcing report |
| SRC-01 | Manufacturer and MPN shall live in KiCad schematic symbol properties as the BOM source of truth; `bom/bom.csv` shall be generated from that source. | BOM export diff/check |
| SRC-02 | Pinouts, absolute limits, recommended operating conditions, and required external components shall be checked against manufacturer datasheets before schematic approval. | Datasheet-backed design review |
| SRC-03 | Hardware deliverables shall remain editable KiCad sources; firmware and app sources shall include repeatable build instructions. | Release artifact review |
| SRC-04 | No release may claim ERC, DRC, firmware build, app build, simulation, bench, or field success without the corresponding captured evidence. | Release checklist review |

## 9. Safety boundaries and required wording

Bench Breathe is a **non-certified advisory trend logger**. It may help a user notice changes and decide to investigate ventilation, but it does not determine whether air is safe, whether exposure is acceptable, or whether protective equipment is required.

- Use only a reputable/certified 5 V USB SELV power source and a known-good cable.
- Do not connect any Bench Breathe input or output to mains, a relay, machinery, ventilation equipment, or a safety interlock.
- Do not use the product as a smoke, fire, gas, carbon-monoxide, medical, or emergency alarm.
- Sensor faults, contamination, placement, airflow, warm-up, drift, and power/network loss can produce missing or misleading readings.
- When a workshop activity may create harmful exposure, follow the material/tool manufacturer guidance and applicable professional safety practice independently of this device.

## 10. Verification classes

Later milestones shall label evidence using these classes so static checks are not confused with physical validation:

1. **Static:** review, lint, ERC, DRC, source inspection, or datasheet comparison.
2. **Simulation:** modeled electrical/thermal behavior with assumptions recorded.
3. **Bench:** measured on a named prototype revision with equipment and conditions recorded.
4. **Field:** observed in representative use over a stated duration; not certification.

Passing one class does not imply another. In particular, ERC/DRC does not prove physical performance, and a bench trend comparison does not establish exposure accuracy or safety fitness.

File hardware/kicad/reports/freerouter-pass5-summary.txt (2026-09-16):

    "total_count": 0
2026-09-16 17:59:16.381 INFO   [275820\55D7D6] Auto-router pass #999 on board '61c072cafddd888b040b3768fcfbf2f8' was completed in 0.42 seconds with the score of 959.62 (15 unrouted), using 70507.14 CPU seconds and 430543 MB memory.

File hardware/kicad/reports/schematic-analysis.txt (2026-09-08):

=== Design Analysis ===

--- certification ---
  [1] INFO CERT-001: Wireless module detected: U1
      Detail: FCC Part 15: Wireless module detected: U1
      Stages: schematic

--- component_derating ---
  [2] INFO VD-004: C4 (100nF 50V X7R) is over-designed for +3V3 (50V on 3.3V rail)
      Detail: 50V-rated capacitor on a 3.3V rail — margin 93.4%.
      Fix:    Consider 10V rating — 50V is significantly over-designed for a 3.3V rail
      Stages: schematic
  [3] INFO VD-004: C8 (100nF 50V X7R) is over-designed for +3V3 (50V on 3.3V rail)
      Detail: 50V-rated capacitor on a 3.3V rail — margin 93.4%.
      Fix:    Consider 10V rating — 50V is significantly over-designed for a 3.3V rail
      Stages: schematic

--- debug ---
  [4] INFO DI-DET: Debug interface J3 (debug): pass
      Detail: Detected debug debug interface on connector J3.
      Stages: schematic, bring_up

--- decoupling ---
  [5] INFO DC-DET: Decoupling on VBUS_FUSED
      Detail: Decoupling capacitors on power rail VBUS_FUSED
      Stages: schematic, layout
  [6] INFO DC-DET: Decoupling on +3V3
      Detail: Decoupling capacitors on power rail +3V3
      Stages: schematic, layout

--- decoupling_coverage ---
  [7] INFO DO-DET: Decoupling coverage on VBUS_FUSED
      Detail: Decoupling frequency coverage for rail VBUS_FUSED
      Stages: schematic
  [8] INFO DO-DET: Decoupling coverage on +3V3
      Detail: Decoupling frequency coverage for rail +3V3
      Stages: schematic

--- i2c_bus ---
  [9] INFO DO-DET: I2C SCL bus on I2C_SCL
      Detail: I2C SCL bus detected with 3 device(s)
      Stages: schematic
  [10] INFO DO-DET: I2C SDA bus on I2C_SDA
      Detail: I2C SDA bus detected with 3 device(s)
      Stages: schematic

--- led_control ---
  [11] INFO LA-AUD: LED D2 (GREEN STATUS) [resistor_limited]
      Detail: LED audit: D2 using resistor_limited drive method.
      Component: D2
      Stages: schematic

--- lifecycle ---
  [12] INFO LC-007: Lifecycle audit not run — --lifecycle flag not passed
      Detail: Component lifecycle / obsolescence audit was not run this session. Reason: --lifecycle flag not passed (run with --lifecycle to query DigiKey / Mouser / LCSC / element14 for obsolescence + operating-temp coverage; requires network + API keys). The review cannot report active / NRND / EOL / obsolete status, last-time-buy windows, or operating-temperature coverage for any BOM part. Treat the lifecycle section of the report as 'not performed'.
      Fix:    Run with --lifecycle (requires DIGIKEY_CLIENT_ID / MOUSER_SEARCH_API_KEY / ELEMENT14_API_KEY env vars; LCSC needs no auth) to populate this section. If intentionally skipped, note it explicitly in the report's 'Not Performed' section.
      Stages: schematic

--- passive_filters ---
  [13] INFO RC-DET: RC filter R4/C5 at 15.92Hz
      Detail: low-pass RC filter
      Stages: schematic
  [14] INFO RC-DET: RC filter R7/C6 at 159154.94Hz
      Detail: low-pass RC filter
      Stages: schematic
  [15] INFO RC-DET: RC filter R8/C9 at 159.15Hz
      Detail: low-pass RC filter
      Stages: schematic

--- power ---
  [16] ERROR PP-001: IC power pin U3.1 (VDD) has no DC path to a power rail (net 'SGP_VDD')
      Detail: Pin U3.1 (VDD) is type=power_in on net 'SGP_VDD'. Graph walk (≤2 hops, rejecting capacitor edges, accepting resistors≤1Ω, inductors, ferrite beads, bridged solder jumpers) did not reach a named power rail. The pin is likely AC-coupled to ground only — the IC will not power up reliably.
      Fix:    Verify the schematic for this pin: the DC route must go through a conducting element (direct wire, 0Ω resistor, inductor, ferrite bead, or bridged solder jumper) — not a capacitor. If the intent was to tie VCC through an LC filter, add the missing inductor or 0Ω in series.
      Stages: schematic

--- power_management ---
  [17] INFO PP-DET: Power path U7 (TPS22919DCKR) [load_switch]
      Detail: Detected load_switch power path component U7.
      Component: U7
      Stages: schematic
  [18] INFO PR-DET: Regulator U5 switching
      Detail: Power regulator (switching) detected
      Component: U5
      Stages: schematic

--- protection ---
  [19] INFO EP-AUD: ESD audit J1 (generic): partial coverage
      Detail: ESD protection audit for generic connector J1: partial coverage.
      Stages: schematic
  [20] INFO EP-AUD: ESD audit J2 (header): none coverage
      Detail: ESD protection audit for header connector J2: none coverage.
      Stages: schematic
  [21] INFO EP-AUD: ESD audit J3 (header): none coverage
      Detail: ESD protection audit for header connector J3: none coverage.
      Stages: schematic
  [22] INFO PD-DET: Protection D1 diode
      Detail: Protection device (diode) on VBUS_FUSED
      Component: D1
      Stages: schematic
  [23] INFO PD-DET: Protection F1 fuse
      Detail: Fuse/polyfuse protection on VBUS_FUSED
      Component: F1
      Stages: schematic
  [24] INFO PD-DET: Protection U6 esd_ic
      Detail: IC-based ESD protection device detected
      Component: U6
      Stages: schematic

--- protocol_integrity ---
  [25] INFO PR-004: USB connector J1: D- (USB_CONN_DM) missing series resistor
      Detail: USB D- on J1 has no series resistor (typically 22R for USB 2.0).
      Fix:    Add a 22R series resistor on D- near the connector.
      Stages: schematic
  [26] INFO PR-004: USB connector J1: D+ (USB_CONN_DP) missing series resistor
      Detail: USB D+ on J1 has no series resistor (typically 22R for USB 2.0).
      Fix:    Add a 22R series resistor on D+ near the connector.
      Stages: schematic

--- sensors ---
  [27] INFO SI-DET: Sensor U4 (SHT40-AD1B-R2) [environmental/i2c]
      Detail: Detected environmental sensor IC U4.
      Component: U4
      Stages: schematic

--- signal_integrity ---
  [28] WARNING PU-001: U2 pin SEL (__unnamed_10) missing pull-down resistor
      Detail: Pin SEL on U2 (SPS30) is connected to net __unnamed_10 but has no pull-down resistor. This pin requires a defined logic level at startup.
      Fix:    Add a 10k pull-down resistor from __unnamed_10 to GND.
      Stages: schematic

--- switching_regulator ---
  [29] INFO DO-DET: Switching regulator U5
      Detail: Switching regulator with inductor L1
      Component: U5
      Stages: schematic

--- usb_compliance ---
  [30] WARNING UC-001: No decoupling capacitor on VBUS at J1
      Detail: USB connector J1: no capacitor found on the VBUS net. USB 2.0 recommends >=1uF bulk + 100nF local decoupling on VBUS.
      Fix:    Add bulk (>=1uF) + 100nF decoupling on VBUS near J1.
      Stages: schematic
  [31] WARNING UC-002: No ESD/TVS protection on VBUS at J1
      Detail: USB connector J1: no TVS diode or ESD array found on the VBUS net. VBUS is exposed to external ESD/surge events.
      Fix:    Add a TVS diode or ESD array on VBUS at J1.
      Stages: schematic

--- usb_data ---
  [32] INFO DO-DET: USB data line USB_DM
      Detail: USB data net USB_DM detected
      Stages: schematic
  [33] INFO DO-DET: USB data line USB_DP
      Detail: USB data net USB_DP detected
      Stages: schematic

--- wireless ---
  [34] INFO WL-001: wifi/ble module U1 (ESP32-C3-WROOM-02-N4)
      Detail: Detected wifi_ble wireless module U1 (ESP32-C3-WROOM-02-N4).
      Stages: schematic, bring_up

Total: 34 (1 error, 3 warnings, 30 info)

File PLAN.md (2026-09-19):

# Bench Breathe — Implementation Plan

## Baseline status

The MVP requirements and safety boundaries are locked in `hardware/requirements.md`. This plan assigns subsystem ownership and evidence gates; it does not claim that hardware, firmware, the companion app, or a physical prototype already exists.

## System architecture

Bench Breathe has three implementation layers and one shared contract:

1. **Hardware platform** — USB 5 V SELV input, protection/regulation, ESP32-C3 module, sensor interfaces, local status/input, debug access, test points, PCB, and enclosure interfaces.
2. **Device firmware** — sensor drivers, deterministic acquisition, quality states, bounded local retention, atomic configuration, local protocol server, serial recovery/export, and reset behavior.
3. **Companion web app** — local setup, status/history visualization, event annotation, configuration, explicit export, and user-facing advisory/safety language.
4. **Versioned protocol contract** — `docs/protocol.md` is finalized contract v1 (issue #7): data shapes, units, validity, errors, limits, authorization, and compatibility rules. The firmware baseline still emits the v0-compatible serial line; adoption is tracked as T-1 in `docs/release-checklist.md`. Ownership is shared across firmware and app changes.

```mermaid
flowchart LR
    USB[5 V USB SELV] --> HW[Protection + regulation]
    PM[PM sensor] --> MCU[ESP32-C3 firmware]
    VOC[VOC sensor] --> MCU
    TH[Temperature / humidity] --> MCU
    HW --> MCU
    MCU --> STORE[Bounded local storage]
    MCU -->|versioned local HTTP/JSON| APP[Local companion web app]
    MCU -->|USB serial fallback| HOST[Local host / recovery tool]
    USER[User] -->|configuration + event labels| APP
    APP -->|explicit CSV/JSON export| FILES[User-controlled local files]
```

### Boundary rules

| Boundary | Producer owns | Consumer owns | Shared checks |
|---|---|---|---|
| Sensors → firmware | Electrical interface and datasheet-qualified signal behavior | Driver cadence, conversion, warm-up/fault handling | Pinout, voltage, bus, timing, and invalid-data tests |
| Firmware → storage | Record schema and commit/rollover behavior | N/A (device-local) | Capacity calculation, reset/power-loss recovery |
| Firmware → app | Versioned API/serial contract, units, limits, status/error responses | Rendering, input validation, retries, accessible user messaging | Contract fixtures and offline behavior tests |
| App → export file | Requested range and user action | File creation/download and presentation | CSV/JSON fixture round trips |
| User → device | Physical setup/reset action | Explicit confirmation and feedback | Setup timeout, reset, and recovery tests |

The firmware remains authoritative for sensor state, timestamps, retained records, configuration limits, and device health. The app must not infer missing values as zero or invent undocumented endpoints. The hardware must not depend on firmware to make a hazardous-voltage situation safe because hazardous-voltage interfaces are outside project scope.

### Companion deployment and local access

The MVP companion is compiled to static assets and served directly by the device. This makes the browser UI and API same-origin and keeps normal operation independent of an internet host or separately installed server. A sustained physical-button action opens a visibly indicated setup window for at most 10 minutes and reveals a single-use, >=128-bit random pairing code over the physically connected USB serial link. The otherwise unauthenticated same-origin pairing endpoint accepts that code only during the window; its first successful exchange returns the per-device API credential, consumes the code, and closes the endpoint. Static assets and minimal non-sensitive health may remain public, but every other API resource requires the credential. State-changing requests also receive same-origin request protection, and USB-serial mutations require a separate recent physical confirmation. The MVP uses local HTTP rather than claiming LAN confidentiality: setup documentation must state that it is for a trusted private LAN only and must not be exposed through port forwarding.

`docs/protocol.md` is finalized contract v1. The access and deployment
constraints above are normative in it (public subset, pairing window,
`X-BB-Auth`, same-origin request protection, button-armed serial
mutations, trusted-LAN-only statement, port-forward prohibition).
Implementation deltas are tracked in `docs/release-checklist.md` (T-1..T-3).

## Technology choices and rationale

- **Controller baseline:** ESP32-C3 module family for local Wi-Fi, USB/serial-capable development paths, cost, and ecosystem. Exact MPN remains a datasheet-backed selection task.
- **Firmware:** C/C++ with a pinned PlatformIO environment and selected ESP-IDF/Arduino framework, chosen during firmware setup and then locked for reproducibility.
- **Sensors:** dedicated PM channel plus VOC and temperature/humidity context, selected against cadence, warm-up, power, airflow, lifecycle, and calibration requirements.
- **Companion app:** TypeScript + Vite local web app for phone/desktop browsers without app-store or cloud-account dependency.
- **Data:** versioned JSON for API/config/state, CSV and JSON for explicit export, bounded device-local retention.
- **Hardware CAD:** editable KiCad project, schematic, and PCB are the hardware source of truth. Manufacturer/MPN properties in the schematic are the BOM source of truth.

## MVP requirements summary

The normative details and acceptance evidence are in `hardware/requirements.md`. Key frozen constraints are:

- USB 5 V SELV only; no mains, relay, actuator, or USB-PD behavior.
- <=250 mA steady-state target and <=500 mA peak input limit.
- PM2.5, VOC proxy/index, temperature, and relative humidity with explicit quality state.
- Default 2 s acquisition tick; configurable 2–60 s.
- Minimum 24 h of 2 s trend records and 30 days of 5 min aggregates/equivalent bounded summaries.
- Offline acquisition and storage; versioned local HTTP/JSON plus USB serial fallback.
- No cloud account, mandatory internet, outbound cloud telemetry, or hidden cloud dependency.
- Advisory trend language only; no certified exposure, medical, emergency, or safe/unsafe claim.
- Prototype BOM target USD 35–60, ceiling USD 75 under the exclusions in `CST-01`.

## Milestones and dependency order

| Milestone | Scope | Exit evidence | Status |
|---|---|---|---|
| M1 — Requirements and risk baseline | Measurable requirements, architecture, safety, risk register | Cross-document review against issue #1 | Baseline documented; implementation evidence not started |
| M2 — Component selection | Select exact controller/sensors/power/protection parts and populate Manufacturer/MPN | Manufacturer datasheets reviewed; pin/electrical decisions cited in `hardware/component-selection.md`; metadata carried in editable KiCad staging sheet | Static selection complete; no circuit/bench evidence |
| M3 — KiCad schematic | Editable project and complete schematic | ERC output, analyzer output, documented exceptions | Complete on issue #3: editable A0 source, clean KiCad 9 ERC, PDF, and static analyzer evidence |
| M4 — BOM export | Generate source-of-truth tracking BOM | `bom/bom.csv` regenerated from schematic properties | Complete on issue #4 with regeneration + no-fabricated-price gate |
| M5 — PCB layout | Place/route board, keepouts, thermal/current paths | DRC and applicable layout analyzer evidence | A0 evidence board (issue #5): DRC 0 violations with 15 documented unrouted stubs — NOT fab release; A1 stub closure is tracked T-4 in `docs/release-checklist.md` |
| M6 — Firmware baseline | Repeatable build/flash, acquisition, quality states, retention, protocol | Unit/contract tests plus documented hardware smoke-test boundary | Baseline complete as static+simulation evidence (issue #6); hardware smoke-test boundary remains bench-gated |
| M7 — Companion app | Setup, status/history, event tags, config, export | Build/lint/tests and protocol fixtures | App MVP + contract v1 complete (issue #7) against dev simulator; real-device integration closes with T-3/bench |
| M8 — Integration and bring-up | Assemble and exercise a named prototype revision | Static, simulation, and bench evidence kept distinct | Bring-up procedure published (issue #8, `docs/bring-up.md`); bench execution awaiting a prototype — no evidence claimed |
| M9 — Mature fabrication/release bundle | Fabrication files, BOM, assembly/bring-up docs, source archive | Regenerated artifacts and release checklist | Checklist published (issue #8, `docs/release-checklist.md`); Gerbers/drill/CPL blocked on T-4 |

M2 depends on M1. M3 depends on M2. M4 depends on M3. M5 depends on M3 and M4. M6 may begin after M2 but hardware claims wait for M3/M5. M7 may scaffold after the protocol boundary is stable, but integration closes only with M6. M8 and M9 depend on all applicable earlier evidence.

## Testing and evidence strategy

- **Requirements/docs:** exact requirement IDs, architecture ownership, safety wording, milestone consistency, and risk mitigations reviewed together.
- **Hardware static:** manufacturer-datasheet pin/electrical checks, ERC, PCB DRC, cross-domain analyzers, BOM regeneration, and fabrication-output inspection.
- **Simulation:** power/transient/thermal or other models where applicable, with assumptions and limitations recorded.
- **Firmware:** pinned build, unit tests for parsing/aggregation/retention/time correction, protocol fixtures, and fault injection for interrupted writes.
- **App:** lint/build/unit tests, accessibility review, invalid/missing-data handling, destructive-action confirmation, and export fixtures.
- **Integration:** offline operation, LAN loss, serial recovery, setup timeout, sensor warm-up/fault, bounded rollover, power interruption, and clock correction.
- **Bench:** current waveform, rail checks, sensor communications, airflow/thermal interaction, and response comparisons on a named hardware revision.
- **Field:** optional representative observations only; never presented as calibration, certification, or evidence that an environment is safe.

## Risk register

| ID | Risk | Likelihood | Impact | Mitigation | Evidence gate |
|---|---|---:|---:|---|---|
| R-01 | Sensor warm-up, drift, contamination, or cross-sensitivity creates false confidence | High | High | Expose quality/warm-up state; use trend/proxy language; follow datasheet conditioning; document placement and maintenance | Datasheet review, quality-state tests, bench comparison |
| R-02 | PM airflow path or enclosure heat biases readings | Medium | High | Separate heat sources from sensing path; preserve airflow; compare open-bench and enclosure behavior | PCB/enclosure review and thermal/response bench test |
| R-03 | Radio plus sensor startup exceeds USB/current regulator capacity | Medium | High | Budget worst-case current and margin; sequence startup if required; measure peak current and brownout | Power analysis, simulation where useful, bench waveform |
| R-04 | Power loss corrupts configuration/history | Medium | High | Atomic records, checksums/versioning, deterministic recovery, oldest-first rollover | Fault-injection and reboot tests |
| R-05 | LAN setup or discovery prevents practical use | Medium | Medium | Time-bounded visible setup mode; retain USB serial setup/recovery/export | Offline/setup/serial integration tests |
| R-06 | Local HTTP service is exposed beyond the intended trusted LAN | Medium | High | Device-hosted same-origin UI; per-device credential issued only in a physical setup window; authorization on all non-minimal resources; physical confirmation for serial mutations; no cloud listener; document cleartext-LAN residual risk and prohibit port forwarding | Authorization/cross-origin tests, network capture, user documentation |
| R-07 | App/firmware protocol drift breaks setup or export | Medium | High | One versioned contract, shared fixtures, breaking-version rule | CI contract tests for both implementations |
| R-08 | Flash endurance or capacity fails retention targets | Medium | Medium | Capacity/endurance calculation, batching/wear strategy, bounded aggregates, accelerated rollover test | Design calculation and firmware storage test |
| R-09 | Sourcing changes invalidate pinout, package, or recommended circuit | Medium | High | Exact Manufacturer/MPN in schematic, cached datasheets, lifecycle/alternate review, no family-only substitution | BOM/datasheet gate before schematic and fabrication |
| R-10 | Documentation implies certified exposure or safety protection | Medium | High | Mandatory advisory wording, prohibited claims, copy review, no automatic control | README/app/release copy review |
| R-11 | USB connector or cable mechanical load damages the board | Medium | Medium | Anchored connector footprint, enclosure strain relief, known-good cable in bring-up | DRC, mechanical inspection, insertion test |
| R-12 | Project reports generated/static evidence as physical validation | Medium | High | Label static/simulation/bench/field evidence separately and bind bench evidence to revision/equipment | Release checklist and PR review |

A risk may be accepted only with a written rationale and residual-risk statement. Missing evidence leaves the related milestone open; it is not converted to a pass by documentation alone.

## Packaging and release policy

- Firmware releases include source, pinned build inputs, binaries only when reproduced, flashing/recovery instructions, and protocol version.
- Companion releases include source, dependency lockfile, reproducible static build instructions, and local-data/export behavior.
- Hardware releases include editable KiCad sources. Gerber, drill, CPL, and BOM files are generated only at the relevant maturity gate.
- `bom/bom.csv` is exported from KiCad schematic properties; preliminary planning spreadsheets are not production BOMs.
- Release notes state which evidence classes were actually completed. No physical-test claim is made until a named prototype is measured.

## Safety and product-claim boundary

Bench Breathe remains SELV/USB-only and advisory. It shall never control mains equipment, ventilation machinery, relays, or safety interlocks. It shall not be presented as a medical device, emergency alarm, industrial hygiene instrument, or guarantee of acceptable exposure. Users must follow material/tool guidance and appropriate ventilation/PPE practices independently of device output.

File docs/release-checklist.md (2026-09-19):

# Fabrication / Release Artifact Checklist

Purpose: define what a **mature release bundle** must contain per subsystem,
track the status of each artifact honestly (generated ≠ verified-on-bench),
and give the exact regeneration commands so any artifact is reproducible from
committed sources (packaging policy: `PLAN.md` §Packaging and release policy).

Status vocabulary: **done** (artifact committed + regeneration proven) ·
**blocked** (named blocker) · **not started** · **bench-gated** (artifact
cannot be honestly completed without a named prototype).

## 1. Hardware

| Artifact | Path | Status | Regeneration |
|---|---|---|---|
| Editable KiCad project | `hardware/kicad/bench-breathe.kicad_pro/.kicad_sch/.kicad_pcb` | done | schematic via `generate_schematic.py`; PCB via `hardware/kicad/scripts/` chain (`hardware/kicad/README.md`, `hardware/pcb-notes.md`) |
| Schematic PDF | `hardware/kicad/exports/bench-breathe-schematic.pdf` | done | `kicad-cli sch export pdf …` |
| ERC report | `hardware/kicad/reports/erc.json` | done — 0 violations (re-run 2026-09-19) | `kicad-cli sch erc …` |
| DRC report | `hardware/kicad/reports/pcb-drc-final.json` (+ `pcb-drc-issue8-recheck.json`) | done as **static evidence** — 0 violations / 15 stubs | `kicad-cli pcb drc …` |
| **Gerbers + drill + board paste (CPL)** | `hardware/kicad/fab/` | **BLOCKED — not exported** | After the 15 stubs close (A1). `pcb-notes.md` §Residuals is explicit: A0 is *not* fab release. Export then via `kicad-cli pcb export gerbers/drill/pos-files`. Exporting Gerbers for an unrouted board would violate R-12 honesty. |
| Fabrication quote / fab parameter check | `docs/` note | not started | requires Gerbers → JLCPCB/PCBWay design-rule check (jlcpcb/pcbway workflow) |
| Assembly drawing / pick-place review | — | not started | after fab export gate |
| Board renders (STEP/photos) | — | not started — placeholder: no render committed | STEP: `kicad-cli pcb export step`; photos are bench-gated |
| Antenna/RF, thermal | — | bench-gated | `pcb-notes.md`: static checks cannot evaluate |

**Gate to unblock hardware fab artifacts:** close the 15 documented stubs
(A1 nudge/manual fanout per `pcb-notes.md` fix table), re-run DRC to 0/0,
then export fab files and record fab-house design-rule confirmation.

## 2. BOM

| Artifact | Path | Status | Regeneration |
|---|---|---|---|
| Stuffed BOM export | `bom/bom.csv` | done — regenerate+gate pass 2026-09-19 (26 lines / 37 refs) | `python3 bom/export_bom.py && python3 bom/verify_bom.py` |
| Non-schematic items | `bom/non-schematic-items.csv` | done (planning-status rows, sourcing TBD) | manual curation (policy: bom/README.md) |
| Order-time stock/price refresh | — | not started (order-time only; policy forbids stale live-scraped numbers in-repo) | distributor skills at order time |
| JLCPCB-format BOM/CPL translation | `bom/` | blocked by fab gate (needs CPL) | `bom` skill `translate_bom_pnp.py` after fab export |

## 3. Firmware

| Artifact | Status | Evidence / gate |
|---|---|---|
| Source + pinned PlatformIO env (`platformio.ini`) | done | build SUCCESS re-run 2026-09-19 |
| Unit/behavior tests | done — 19/19 (simulation class) | `pio test -e native` |
| Reproducible binary | not started — no tag; binaries only when reproduced from a tag (policy) | after tag `firmware-v0.1.0` once bench Step 4 passes |
| Flashing/recovery instructions | done (documented, bench-gated execution) | `firmware/README.md` §Flashing + `docs/bring-up.md` §4 |
| Protocol v1 serial adoption (`protocol:"v1"`, `reason`, serial command set) | not started — known delta in `docs/protocol.md` | tracked below (Open tracked items T-1) |
| Full DAT-01 mmap flash partition | not started | firmware README open item (T-2) |
| Release notes with evidence classes | not started — first release notes must name prototype + evidence classes | at first tag |

## 4. Companion app

| Artifact | Status | Evidence / gate |
|---|---|---|
| Static assets (`app/public/`) | done | zero-dep, no build step (COM-05) |
| Contract tests | done — 13/13 (simulation class) | `cd app && npm test` |
| Dev simulator | done — `app/dev/stub-server.mjs` (explicitly a simulator) | — |
| Device-side HTTP serving + Wi-Fi provisioning | not started | app runs against stub today (T-3) |
| Release bundle / notes | not started | blocked on device HTTP + bench |

## 5. Integration / docs

| Artifact | Status |
|---|---|
| Protocol contract v1 | done — `docs/protocol.md` (final, v0→v1 breaking list + known deltas) |
| Bring-up guide + wiring/pinouts + calibration + troubleshooting | done (this PR) — `docs/bring-up.md`; bench cells deliberately unexecuted |
| Bench evidence records | bench-gated — attach to `docs/bring-up.md` §9 ledger |
| Field observations | optional; never claimed |

## 6. Release gate (all must read done or explicitly waived in writing)

- [x] Editable KiCad sources
- [x] Clean ERC + static validator
- [ ] DRC 0 violations **and 0 unresolved stubs** ← current blocker
- [ ] Gerbers/drill/CPL exported + fab-rule checked
- [ ] `bom/bom.csv` gate pass (done at HEAD; re-check at release)
- [ ] Firmware tag + reproduced binary + bench Step 4 pass
- [ ] Protocol v1 serial adoption in firmware (T-1)
- [ ] Device HTTP serving + app paired against real device (T-3)
- [ ] Bring-up bench record for a named revision (Steps 3–6, 8)
- [ ] Release notes stating completed evidence classes only (R-12)

## Open tracked items (absorbed from issue #8 body — each needs its own issue/PR)

| ID | Item | Owner track |
|---|---|---|
| T-1 | Firmware serial protocol-v1 adoption: `"protocol":"v1"`, per-channel `reason`, serial command set (GET/SET/TIME/PAIR/EXPORT/RESET, `ARM 30`) | firmware |
| T-2 | DAT-01 full-capacity mmap flash partition + power-loss atomicity fault injection | firmware |
| T-3 | Device-side HTTP serving + Wi-Fi provisioning/setup mode | firmware/app |
| T-4 | A1 stub closure (15 documented, fixes pre-registered in `pcb-notes.md`) → fab export gate | hardware |
| T-5 | CC ADC window calibration vs divider + ESP32-C3 ADC accuracy (bring-up Step 3.7) | bench |
| T-6 | Bench record of Steps 3–6/8 on a named prototype (R-03/R-12 evidence) | bench |

## Placeholder media (explicitly marked until replaced)

- Assembly photo — `docs/bring-up.md` §1
- Bench captures (current waveform, I²C scan, console) — `docs/bring-up.md` §9
- Board renders/STEP — no image committed anywhere in the repo; renders will
  live beside fab files once exported

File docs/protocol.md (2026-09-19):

# Device ↔ App Protocol — Contract v1 (FINAL)

Status: **finalized contract** (COM-04). This document is the single
versioned contract for HTTP and USB-serial data shapes, units, limits,
errors, authorization, and compatibility between Bench Breathe firmware
and the companion app. Breaking changes require `/api/v2/...` (HTTP) or a
`protocol: "v2"` serial banner, plus migration notes in a new
`## v1 → v2 migration` section.

Reference implementations of this contract at finalize time:

| Surface | Reference | Evidence class |
|---|---|---|
| Serial NDJSON health line | `firmware/src/core/health_line.cpp` (baseline emits `protocol:"v0"` field; see Known deltas) | simulation (unit-tested) |
| HTTP API + serial commands | `app/dev/stub-server.mjs` (dev device simulator) | contract tests `app/test/contract.test.mjs` |
| Client | `app/public/` companion web app | contract tests |

## Version history

| Version | Date | Change |
|---|---|---|
| v0 (draft) | 2026-09-04 | Initial draft resource list. |
| **v1 (final)** | 2026-09-19 | Finalize HTTP shapes/limits/errors, add authorization (COM-07), time control, history/export/event wire shapes, serial command set. |

### v0 → v1 breaking changes (explicit)

1. **Authorization.** v0 assumed open local access. v1 requires a
   per-device bearer credential on every API resource except the
   documented public subset (COM-07). A v0 client cannot use a v1 device.
2. **Health response split.** v0 `GET /api/v1/health` returned everything.
   v1 splits it: a *public, non-sensitive* health subset (no sensor values,
   no label) and the full status inside `GET /api/v1/live`.
3. **Error shape.** v0 left errors undefined. v1 fixes a single error
   envelope and error-code registry (below).
4. **Null-channel shape.** v0 said "explicit `null` + reason". v1 fixes
   the exact per-channel object: `{"status","value","unit","reason"}`.
   `value` is JSON `null` exactly when `status != "ready"`.
5. **Time control added.** `POST /api/v1/time` (clock-quality semantics
   `unset/estimated/network`). New capability, not a break.
6. **Path prefix.** All resources live under `/api/v1/` (v0 draft already
   used this prefix; now normative).

### Known deltas at finalize time

- Firmware baseline (`0.1.0-baseline`) streams serial NDJSON health lines
  with `"protocol":"v0"` and no `reason` field on null channels. The wire
  *field names and enum strings* are unchanged in v1; firmware adoption of
  `"protocol":"v1"` + `reason` + the serial command set is a firmware
  follow-up (bench-gated, tracked for #8 bring-up). The app tolerates
  both by treating a missing `reason` on a null channel as
  `"not_yet_measured"`.
- The device does not yet serve HTTP itself (Wi-Fi provisioning + flash
  partition work); the app therefore runs against the dev stub today.

## Goals
- Deterministic, versioned, local-first communication.
- Safe degradation when network features are unavailable (USB-serial
  fallback covers setup, health, config recovery, export — COM-03).
- No mandatory internet dependency; no outbound cloud connections (COM-08).

## Transport
- **Primary:** HTTP/1.1 + JSON on the local network. The device serves the
  compiled app itself; all API requests are **same-origin**; wildcard CORS
  is prohibited (COM-05).
- **Fallback:** USB serial (CDC, 115200 baud), line-oriented commands and
  NDJSON responses (below).
- MVP HTTP traffic is **not confidential** against an attacker already on
  the trusted private LAN (COM-09). The device must never be port-forwarded
  or internet-exposed, and the UI must not describe it as internet-safe.

## Authorization (COM-06 / COM-07)

- After a sustained physical-button action, USB serial prints a
  **single-use pairing code** (≥128 bits CSPRNG entropy, valid ≤10 min):
  `PAIR <code>`.
- During that window, `POST /api/v1/pair` (unauthenticated, same-origin)
  exchanges the code for the per-device API credential. The first
  successful exchange consumes the code and closes the pairing endpoint.
- All protected requests carry `X-BB-Auth: <token>`.
- State-changing HTTP requests additionally require
  `X-BB-Req: bb` (same-origin request protection — a custom header forces
  a CORS preflight, which same-origin usage never triggers).
- USB-serial mutation commands (`SET`, `TIME`, `PAIR`, `RESET`) require a
  fresh physical-button confirmation: valid for 30 s after a button hold,
  signalled on the serial stream as `ARM 30`.
- Factory reset replaces all pairing material and returns the device to the
  unprovisioned state.

**Public (unauthenticated) subset:**
`GET /api/v1/health`, `POST /api/v1/pair`, and static app assets.
Everything else under `/api/v1/` requires the credential.

## Common shapes

### Error envelope (every non-2xx HTTP response)
```json
{"error": {"code": "string", "message": "string", "details": {}}}
```
Error-code registry (stable strings):

| code | HTTP | Meaning |
|---|---|---|
| `unauthorized` | 401 | missing/invalid `X-BB-Auth` |
| `pairing_closed` | 409 | pairing endpoint not armed (no button action / expired) |
| `pairing_invalid` | 403 | wrong or already-consumed code |
| `interval_out_of_range` | 422 | `interval_ms` outside 2000–60000 (rejected, never clamped — SNS-03) |
| `label_too_long` | 422 | label > 31 UTF-8 bytes |
| `time_invalid` | 422 | `wall_us` not a non-negative integer |
| `event_tag_invalid` | 422 | event tag shape violation |
| `unknown_path` | 404 | not a known resource |
| `device_error` | 500 | internal failure |

### Channel object (SNS-01/SNS-04)
```json
{"status": "ready|warming|fault|unknown",
 "value":  12.3,            // JSON null unless status == "ready"
 "unit":   "ug_m3|ticks|c|pct",
 "reason": "none|warming|sensor_fault|power_gated|not_yet_measured|stale_beyond_limit"}
```
Missing/invalid channels are explicit `null` + `reason`, never silently
dropped and never zeros-as-data. Units are fixed per channel id:
`pm25` µg/m³, `voc_raw` SGP40 SRAW_VOC ticks (raw proxy, not index),
`temperature_c` °C, `humidity_pct` %RH.

### Clock quality (SNS-06)
`"clock": "unset" | "estimated" | "network"` — no wall source / set once,
never validated (e.g. serial or HTTP time) / network-synced. Records with
`"clock":"unset"` carry `wall_us = 0`; clients order them by `seq`.

## HTTP resources (all under `/api/v1/`)

### `GET /health` — public health subset (COM-07)
Non-sensitive only; no sensor values, no device label.
```json
{"protocol":"v1","fw":"0.1.0-baseline","uptime_s":123,
 "mode":"full|recovery|suspended|error","source":"no_vbus|default_cc|cc_1a5|cc_3a|unknown_cc",
 "clock":"unset|estimated|network","paired":false,
 "storage":{"raw_used":0,"raw_capacity":0,"agg_used":0,"agg_capacity":0}}
```

### `POST /pair` — body `{"code":"<pairing code>"}` → `200 {"token":"...","schema":1}`
`409 pairing_closed` when unarmed, `403 pairing_invalid` on wrong/consumed
code. Response sets no cookies; the client stores the token.

### `GET /config` / `PUT /config`
```json
{"schema":1,"interval_ms":2000,"label":"bench-breathe"}
```
PUT is validated (`interval_out_of_range`, `label_too_long`) and applied
atomically; the response is the committed config.

### `POST /time` — body `{"wall_us": 1767225600000000}`
Sets wall clock; resulting quality is `estimated`. → `200` health-like
echo `{"clock":"estimated","wall_us":...}`.

### `GET /live` — latest sample + full status
```json
{"protocol":"v1","seq":1234,"wall_us":1767225600000000,"clock":"estimated",
 "uptime_s":123,"mode":"full","source":"default_cc",
 "storage":{"raw_used":100,"raw_capacity":4096,"agg_used":10,"agg_capacity":288,
            "oldest_seq":1,"newest_seq":1234},
 "channels":{"pm25":{...channel},"voc_raw":{...},"temperature_c":{...},"humidity_pct":{...}}}
```

### `GET /history?from=<wall_us>&to=<wall_us>` — bounded range query
Omitting both returns the retained window. Response:
```json
{"protocol":"v1","from":0,"to":0,"clock":"estimated","count":2,
 "records":[{"seq":1,"wall_us":0,"clock":"unset",
             "channels":{"pm25":{...},"voc_raw":{...},"temperature_c":{...},"humidity_pct":{...}}}]}
```
Records are ordered by ascending `seq`. `from`/`to` filter on `wall_us`
when `clock != "unset"` (records with unset wall clock are included only
when both bounds are omitted).

### `POST /events` — body `{"tag":"fan_on","note":"optional ≤200 bytes"}`
Tag must match `[a-z][a-z0-9_]{0,31}`; `session_start`, `window_open`,
`fan_on` are the reserved MVP tags but any valid tag is accepted.
→ `201 {"protocol":"v1","event_id":3,"mono_us":987654,"tag":"fan_on","note":""}`.
`GET /events` returns `{"protocol":"v1","count":n,"events":[same shape]}`.

### `GET /export.csv` and `GET /export.json` — explicit user export only
Both carry full retained history + events; the app downloads them verbatim.

CSV: first line is a metadata comment line, then a header row:
```
# bench-breathe export protocol=v1 clock=estimated fw=0.1.0-baseline exported_wall_us=1767225600000000 count=2
seq,wall_us,clock,pm25_ug_m3,voc_raw_ticks,temperature_c,humidity_pct
1,,unset,,,,
2,1767225600000000,estimated,12.30,214,25.40,48.10
```
Unset channel values are empty CSV fields. JSON:
```json
{"protocol":"v1","exported_wall_us":1767225600000000,"clock":"estimated",
 "fw":"0.1.0-baseline","count":2,
 "records":[{...history record shape...}],
 "events":[{...event shape...}]}
```

## USB-serial fallback (COM-03)

Line protocol over USB CDC @115200. One command per line (CRLF);
responses are NDJSON lines, terminated for commands by a status line
`OK` or `ERR <code>`. The device also free-runs one health NDJSON line
per second (the baseline line, field-compatible with `GET /live` minus
`seq`/`channels` nesting unchanged).

Commands (mutations require fresh button-arm, `ARM 30`):

| Command | Response |
|---|---|
| `GET health` | full serial health NDJSON line, `OK` |
| `GET config` | config NDJSON, `OK` |
| `SET config interval_ms=<n> [label=<s>]` | committed config NDJSON, `OK`, or `ERR interval_out_of_range` / `ERR label_too_long` / `ERR not_armed` |
| `TIME <wall_us>` | `{"clock":"estimated",...}`, `OK` |
| `PAIR` | `PAIR <code>` (arms pairing endpoint ≤10 min), requires arm |
| `GET history` | one NDJSON history record per line, then `OK` |
| `EXPORT csv` | CSV lines exactly as `GET /export.csv`, then `OK` |
| `RESET` | `{"reset":true}`, `OK`, requires arm |

`not_armed` serial error string mirrors the HTTP registry style.

## Data quality and status semantics (normative)
- Sensor class reports `ready`, `warming`, `fault`, or `unknown`.
- `value` non-null ⇔ `status:"ready"`; every non-ready channel carries a
  non-`none` `reason`.
- Time source and clock-quality state are included in export metadata.
- Exports are explicit user actions only; the app never uploads anything.

## Data ownership and privacy
- The user owns all captured data. No cloud, no telemetry, no analytics
  (in-app or device-side). All state (device URL, token) stays in browser
  `localStorage` on the user's machine; history stays on the device until
  the user exports it. Forgetting a device (Forget button) clears local
  state; factory reset on the device clears device-side data.
- Threat model: trusted private LAN only; MVP traffic is not encrypted —
  do not port-forward (COM-09).

## Compatibility rules
- Additive fields may appear at any time; clients must ignore unknown
  fields.
- Enum strings are stable wire values and never renumbered/reused; new
  enum values are minor changes, clients must degrade to `unknown`.
- Removal/renaming of fields, enum semantics changes, or auth changes are
  breaking → `/api/v2` (HTTP) or `protocol:"v2"` (serial) + this document
  gaining a migration section.
- `schema` in config responses allows config-shape evolution without an
  API version bump.

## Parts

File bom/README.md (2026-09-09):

# BOM workflow

The **editable KiCad schematic** (`hardware/kicad/bench-breathe.kicad_sch`) is
the single source of truth for this BOM. Sourcing data lives in schematic
symbol properties (`Manufacturer`, `MPN`, `LCSC`, `Package`, `Datasheet`,
`BOM Comments`) and is exported — never hand-maintained — into:

| File | Role |
|---|---|
| `bom.csv` | Generated stuffed-BOM export from the schematic (this is the committed artifact). |
| `export_bom.py` | Reproducible exporter: `kicad-cli sch export bom` (ungrouped) + in-script merge of identical parts, supplier/pricing annotation. |
| `verify_bom.py` | Gate script: proves `bom.csv` is exactly the in-BOM symbol set of the schematic with no fabricated prices. |
| `preliminary-bom.csv` | Historical issue-#2 candidate list, now annotated with `Schematic_Refs` and `Reconciliation` columns. |
| `non-schematic-items.csv` | PCB fab, enclosure, cables, fasteners, adapter, power supply — items not on any schematic symbol, each with explicit planning status. |

## Regenerate

From the repository root (requires `kicad-cli` on PATH, tested with KiCad 9.0.9):

```bash
python3 bom/export_bom.py          # rewrites bom/bom.csv
python3 bom/verify_bom.py          # fails non-zero on any inconsistency
```

## Sourcing and pricing policy (no fabricated claims)

- `Supplier_Source` contains an LCSC part number **only** where the schematic
  carries a manufacturer-validated `LCSC` property (see
  `hardware/component-selection.md`); every other row is
  `TBD - no validated source`.
- `Estimated_Unit_Cost_USD` is populated only for those validated parts, from
  the dated LCSC catalog snapshot (2026-09-05) recorded in
  `hardware/component-selection.md`. The `Price_Basis` column names that
  source on every priced row. All other rows are `TBD`.
- These are volatile planning figures, **not purchase quotes**. Re-run
  authorized-channel stock, pricing, and lifecycle checks at order time.
- Stock quantities are intentionally absent from this export; they go stale
  and must be re-queried live before ordering.

## Scope boundaries

The board is a SELV/USB-only device (5 V USB-C input, no mains control, no
medical/life-safety claims). Non-schematic support items (enclosure, cables,
fasteners, wall adapter, debug adapter) are tracked with explicit
`UNRESOLVED - live sourcing required` status rather than guessed parts.

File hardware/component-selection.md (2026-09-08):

# Datasheet-backed component selection

Status: **M2 component selection retained in the complete M3 schematic; physical validation not started**

Snapshot date: **2026-09-07 UTC**

This document records the exact parts selected for the first schematic pass. Manufacturer datasheets are the electrical ground truth. The editable schematic at [`kicad/bench-breathe.kicad_sch`](kicad/bench-breathe.kicad_sch) now carries functional symbols, application circuits, footprints, named nets, and `Manufacturer`, `MPN`, `Datasheet`, `Package`, and `BOM Comments` properties plus `LCSC` only for manufacturer-validated matches. Issue #3 adds the complete A0 electrical capture while retaining the M2 selections.

## Selected parts

| Ref | Function | Manufacturer / MPN | Package or interface | Why selected |
|---|---|---|---|---|
| U1 | Controller and Wi-Fi | Espressif Systems `ESP32-C3-WROOM-02-N4` | 19-pad 18.0 x 20.0 x 3.2 mm module, PCB antenna | Native USB D-/D+ on module pins 13/14, 4 MB flash, 15 GPIOs, local Wi-Fi, documented antenna keepout |
| U2 | PM1/PM2.5/PM4/PM10 channel | Sensirion `SPS30` | Module; JST ZHR-5 mating connector; UART or I2C | Manufacturer-supported particulate module, 1 s sampling, documented warm-up/lifetime and 3.3 V-compatible interface levels |
| U3 | VOC proxy/index channel | Sensirion `SGP40-D-R4` | DFN-6, 2.44 x 2.44 x 0.85 mm, center pad | Dedicated VOC raw signal and Sensirion VOC Index algorithm; accepts humidity/temperature compensation |
| U4 | Temperature/humidity context | Sensirion `SHT40-AD1B-R2` | DFN-4, 1.5 x 1.5 x 0.5 mm, open cavity | 0x44 I2C device, low measurement current, supplies compensation inputs for U3 |
| U5 | 5 V to 3.3 V conversion | Texas Instruments `TPS62162DSGR` | WSON-8 exposed pad (DSG), 2.0 x 2.0 mm | Fixed 3.3 V, 1 A synchronous buck; 3–17 V input withstands the selected VBUS TVS clamp |
| U6 | USB signal/CC ESD | Texas Instruments `TPD4E05U06DQAR` | USON-10 (DQA), 2.5 x 1.0 mm | Four 0.5 pF-class channels for D+, D-, CC1, and CC2; IEC 61000-4-2 system-level rating |
| U7 | Switched 5 V PM rail | Texas Instruments `TPS22919DCKR` | SC-70-6 (DCK), 2.1 x 2.0 mm | MCU-controlled PM power removal, controlled rise time, output discharge, and 1.5 A capacity |
| J1 | USB-C USB 2.0 receptacle | GCT `USB4105-GF-A` | Right-angle top-mount hybrid SMT/THT | USB 2.0 data contacts, mechanically staked shell, 5 A aggregate VBUS contact test margin; no PD controller |
| F1 | Input overcurrent fault protection | Bourns `MF-MSMF050-2` | 1812 | 0.50 A hold / 1.00 A trip PPTC for fault protection |
| D1 | VBUS transient clamp | Diodes Incorporated `SMBJ5.0A-13-F` | SMB / DO-214AA, unidirectional | 5.0 V working standoff and 9.2 V maximum rated-pulse clamp, below U5's 17 V recommended maximum |

## Manufacturer-datasheet checks

### U1 — ESP32-C3-WROOM-02-N4

Source: [ESP32-C3-WROOM-02 datasheet v1.7](https://documentation.espressif.com/esp32-c3-wroom-02_datasheet_en.pdf).

- Table 1-1 (p. 3) identifies the N4 variant as 4 MB Quad-SPI flash, -40 to 85 °C, and 18.0 x 20.0 x 3.2 mm.
- Table 3-1 (pp. 10–11) maps module pin 13 to GPIO18/USB_D- and pin 14 to GPIO19/USB_D+; pins 1, 9, and 19 are 3V3/GND.
- Table 6-2 (p. 22) requires 3.0–3.6 V and an external supply capable of at least 0.5 A.
- Table 6-4 (p. 23) reports 345 mA peak for 802.11b TX at 20.5 dBm and 84 mA peak RX for HT40.
- Layout must enforce the datasheet antenna keepout. USB D+/D- and boot strapping on GPIO2/8/9 require explicit issue-#3 review.

### U2 — SPS30

Source: [SPS30 datasheet v2.0 D1](https://sensirion.com/media/documents/8600FF88/64A3B8D6/Sensirion_PM_Sensors_Datasheet_SPS30.pdf).

- Table 2 (p. 3): 4.5–5.5 V supply, 55 mA typical/65 mA maximum in measurement mode, 80 mA maximum during the first 200 ms of fan start.
- Table 4 (p. 4): pin 1 VDD, pin 2 RX/SDA, pin 3 TX/SCL, pin 4 SEL, pin 5 GND. The interface accepts 3.3 V LVTTL levels.
- The corresponding cable-side connector is JST ZHR-5. Pull SEL low for I2C or leave it floating for UART.
- Table 1 (p. 2): 1 s sampling interval, typical stable-output start-up of 8–30 s depending on concentration, and calculated lifetime over 10 years at 24 h/day.
- The housing/shield is internally tied to signal GND; do not create a second unintended chassis-current path.

### U3 — SGP40-D-R4

Source: [SGP40 datasheet v1.2](https://sensirion.com/media/documents/296373BB/6203C5DF/Sensirion_Gas_Sensors_Datasheet_SGP40.pdf).

- Table 2 (p. 4): VDD/VDDH 1.7–3.6 V; at 3.3 V continuous operation is 2.6 mA typical/3.0 mA maximum.
- Table 6 and Figure 5 (p. 7): pin 1 VDD, 2 VSS, 3 SDA, 4 GND, 5 VDDH, 6 SCL; VDD needs RC decoupling and VDDH needs a recommended 1 µF capacitor. The center pad is GND.
- Section 4.2 (p. 11): I2C address `0x59`, standard/fast mode up to 400 kHz.
- Section 3 (pp. 9–10): provide current RH/T values for compensation and feed the 1 s raw signal into Sensirion's Gas Index Algorithm. Warm-up/baseline quality must be surfaced; the output remains a VOC proxy/index, not a safety measurement.
- Table 18 (p. 17) identifies orderable `SGP40-D-R4`, product number 3.000.384.

### U4 — SHT40-AD1B-R2

Source: [SHT4x datasheet v6.4](https://sensirion.com/media/documents/33FD6951/6555C40E/Sensirion_Datasheet_SHT4x.pdf).

- Table 4 (p. 8): 1.08–3.6 V supply; 500 µA maximum measurement current with heater off; 2.2 µA average at one high-repeatability measurement per second.
- Table 6 (p. 10): -40 to 125 °C operating absolute limit. Bench Breathe remains constrained to 10–35 °C and 20–80% RH by `ENV-01`.
- Figure 18 (p. 16): pin 1 SDA, 2 SCL, 3 VDD, 4 VSS. The `A` nomenclature fixes I2C address `0x44`.
- The open-cavity package requires airflow exposure, no copper under the sensor except pads, and separation from MCU/regulator heat. The 200 mW heater can draw 100 mA maximum and is not a normal continuous operating mode.

### U5 — TPS62162DSGR

Source: [TPS6216x datasheet rev. E](https://www.ti.com/lit/ds/symlink/tps62160.pdf).

- Table 5 (p. 4) identifies TPS62162 as fixed 3.3 V in WSON-8.
- Section 7.3 (p. 5): 3–17 V recommended input; family supports up to 1 A continuous output.
- Table 6 (p. 4): pins 1 PGND, 2 VIN, 3 EN, 4 AGND, 5 FB, 6 VOS, 7 SW, 8 PG; exposed pad must be soldered to AGND. TI recommends grounding FB on fixed-output versions.
- Issue #3 must copy the typical application values and tight switch-loop layout from the current datasheet, then verify inductor saturation/current rating and capacitor derating.

### U6/U7/J1/F1/D1 — input and interface protection

- [TPD4E05U06 datasheet rev. 2024](https://www.ti.com/lit/ds/symlink/tpd4e05u06.pdf), pp. 1, 4, 6: four protected channels, approximately 0.5 pF loading, 5.5 V working voltage, ±12 kV contact/±15 kV air IEC 61000-4-2 rating. Place at J1; DQA pins 1/2/4/5 are channels and pins 3/8 are GND.
- [TPS22919 datasheet rev. B](https://www.ti.com/lit/ds/symlink/tps22919.pdf), pp. 1, 3–4: 1.6–5.5 V, 1.5 A continuous, active-high ON, controlled rise time, short/thermal self-protection. Pin map is 1 IN, 2 GND, 3 ON, 4 NC, 5 QOD, 6 VOUT.
- [USB4105 product specification rev. A3](https://media.digikey.com/pdf/Data%20Sheets/GCT%20PDFs/USB4105_Spec.pdf), pp. 2–4: USB 2.0 Type-C receptacle, -40 to 85 °C, 5 A aggregate VBUS current test, and 20,000-cycle durability. This project is nevertheless limited to 5 V and 500 mA peak.
- [MF-MSMF datasheet](https://bourns.com/docs/product-datasheets/mf-msmf.pdf), electrical table p. 1: MF-MSMF050 has 15 V maximum, 0.50 A hold, 1.00 A trip, and -40 to 85 °C operation. It is a slow resettable fault device, **not** a precise USB current-limit switch.
- [Diodes Incorporated SMBJ datasheet DS19002 rev. 20](https://www.diodes.com/assets/Datasheets/ds19002.pdf), pp. 1–3: orderable `SMBJ5.0A-13-F` is the unidirectional tape-and-reel variant with 5.0 V working standoff, 6.4–7.23 V breakdown, 9.2 V maximum clamp at the rated pulse, and 600 W peak pulse power. KiCad uses `Device:D_Zener`; pin 1 is K/cathode for VBUS and pin 2 is A/anode for GND.

## Static power budget

This is a conservative arithmetic check, not simulation or a bench measurement.

| Case | Inputs | Estimated USB input |
|---|---|---:|
| Normal measurement/RX envelope | U1 84 mA at 3.3 V; U3 2.6 mA; U4 2.2 µA average; U2 65 mA maximum; assume only 85% buck efficiency | about 132 mA plus LEDs/logic |
| Concurrent worst listed loads | U1 345 mA TX + U3 3 mA + U4 100 mA maximum heater at 3.3 V; U2 80 mA fan start at 5 V; assume 85% buck efficiency | about 428 mA plus LEDs/logic |

The 1 A U5 output rating covers the listed 448 mA 3.3 V aggregate. The peak estimate leaves only about 72 mA before the 500 mA project ceiling, so firmware must not run the SHT40 high-power heater during PM fan start/high-power Wi-Fi activity. Issue #3 must complete the passive/load budget; issue #6 must implement source-state gating; named-revision bench measurements must confirm average and peak current. F1 does not enforce this ceiling.

## Availability and lifecycle snapshot

Queries were run on 2026-09-07 UTC. LCSC fields below come from the component catalog snapshot dated 2026-09-05; DigiKey observations come from exact manufacturer/MPN product listings returned by search on 2026-09-07. Quantities and prices are volatile planning evidence, not purchase quotes. An LCSC number is written into KiCad only when both MPN **and manufacturer** match.

| MPN | Manufacturer-validated source | Snapshot | Reported status/stock and unit field | Disposition |
|---|---|---|---|---|
| ESP32-C3-WROOM-02-N4 | LCSC C2934560 | 2026-09-05 | Active; 3,702; USD 3.2912 | Accepted; exact Espressif match |
| SPS30 | [Sensirion current product catalog](https://sensirion.com/products/catalog/SPS30) and [DigiKey exact Sensirion listing](https://www.digikey.com/en/products/detail/sensirion-ag/SPS30/9598990) | 2026-09-07 | Current manufacturer catalog and buy/ship listing present; numeric stock/price not captured | LCSC C5900567 was **not** assigned because its catalog manufacturer is blank; formal PCN/EOL review remains an order-time check |
| SGP40-D-R4 | LCSC C2874215 | 2026-09-05 | Active; 2,499; USD 6.8654 | Accepted; exact Sensirion match |
| SHT40-AD1B-R2 | LCSC C2909890 | 2026-09-05 | Active; 20,692; USD 2.0288 | Accepted; exact Sensirion match |
| TPS62162DSGR | LCSC C40256 | 2026-09-05 | Active; 439; USD 0.9697 | Accepted; exact TI match |
| TPD4E05U06DQAR | LCSC C138714, [TI product/buy page](https://www.ti.com/product/TPD4E05U06/part-details/TPD4E05U06DQAR), and [DigiKey exact TI listing](https://www.digikey.com/en/products/detail/texas-instruments/TPD4E05U06DQAR/3996774) | 2026-09-05 / 2026-09-07 | Active; 94,387; USD 0.0819; current TI ordering page and exact distributor listing present | Accepted; exact TI match. Candidate C22390021 was rejected because it resolves to DOWO, not TI; formal PCN/EOL review remains an order-time check |
| TPS22919DCKR | LCSC C2149796 | 2026-09-05 | Active; 35,367; USD 0.1378 | Accepted; exact TI match |
| USB4105-GF-A | LCSC C3020560 | 2026-09-05 | Active; 11,505; USD 1.0624 | Accepted; exact Global Connector Technology match |
| MF-MSMF050-2 | LCSC C17313 | 2026-09-05 | Active; 19,184; USD 0.0690 | Accepted; exact Bourns match |
| SMBJ5.0A-13-F | LCSC C110528 and [DigiKey exact Diodes Incorporated listing](https://www.digikey.com/en/products/detail/diodes-incorporated/SMBJ5-0A-13-F/725039) | 2026-09-05 / 2026-09-07 | Active; 6,839; USD 0.1019; exact distributor buy/ship listing present | Accepted; exact Diodes Incorporated match and unique orderable suffix |

Catalog/API source: `https://jlcsearch.tscircuit.com/api/search?q=<MPN>&limit=10&full=true`, cross-checked with exact-code resolver records before writing LCSC properties. Manufacturer names and electrical/package claims come from manufacturer documents, not distributor descriptions. The nine manufacturer-validated LCSC one-unit fields total **$14.61**, excluding SPS30, passives, PCB, cable, enclosure, and accessories; therefore no complete BOM-cost claim is made. Re-run authorized-channel stock, pricing, and PCN/EOL/NRND checks immediately before ordering. No long-term supply guarantee is claimed.

## Remaining layout, firmware, and physical-validation blockers

1. USB-C CC1/CC2 advertisement voltages are routed to ESP32 ADC-capable GPIO0/GPIO1 and the PM rail defaults off in hardware, but USB configuration/suspend state, current ceilings, droop handling, and brownout-loop prevention remain firmware/bench gates.
2. ESD/TVS proximity, USB routing, buck switch-loop geometry, antenna keepout, sensor thermal separation, and exposed-sensor copper/contamination controls remain PCB-layout work for issue #5.
3. U3/U4 are small exposed-sensor DFNs with contamination, soldering, copper, and thermal-placement constraints. The project-local SGP40 land pattern follows Sensirion Figure 14 and KiCad upstream review MR 2511; manufacturing and assembly suitability remain unproven.
4. The SPS30 module, ZHR-5 mating cable/housing, and board-side J2 connector are required BOM/system items and must not be omitted from issue #4.
5. Static power arithmetic and clean ERC do not satisfy simulation, bench, or field evidence. No prototype has been built or measured.

## Evidence classification

- **Static performed:** manufacturer-PDF review, exact-MPN metadata population, live availability query, complete schematic pin/net validation, and clean KiCad 9 ERC.
- **Simulation:** not performed in issue #3.
- **Bench:** not performed; no prototype exists.
- **Field:** not performed.

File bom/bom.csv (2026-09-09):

Refs | Qty | Value | Description | Footprint | Package | Manufacturer | MPN | Supplier_Source | Estimated_Unit_Cost_USD | Price_Basis | DNP | Notes
C1,C3,C10 | 3 | 10uF 10V X5R |  | Capacitor_SMD:C_1206_3216Metric | C_1206_3216Metric | Murata | GRM31CR61A106KA01L | TBD - no validated source | TBD | TBD - live sourcing required at order time |  | Buck input capacitor; close to VIN/PGND. | ESP32 local 3.3 V bulk capacitor. | Local switched PM rail bulk; controlled rise limits inrush.
C2 | 1 | 22uF 16V X5R |  | Capacitor_SMD:C_1206_3216Metric | C_1206_3216Metric | Murata | GRM31CR61C226ME15L | TBD - no validated source | TBD | TBD - live sourcing required at order time |  | Buck output capacitor; 22 µF nominal per TI recommended combination.
C4,C6,C8,C9 | 4 | 100nF 50V X7R |  | Capacitor_SMD:C_0603_1608Metric | C_0603_1608Metric | Murata | GRM188R71H104KA93D | TBD - no validated source | TBD | TBD - live sourcing required at order time |  | ESP32 high-frequency supply bypass. | SGP40 filtered VDD decoupling after 10 Ω series resistor. | SHT40 local VDD bypass. | Button hardware debounce; firmware still applies bounded debounce.
C5,C7 | 2 | 1uF 16V X7R |  | Capacitor_SMD:C_0603_1608Metric | C_0603_1608Metric | Murata | GRM188R71C105KA12D | TBD - no validated source | TBD | TBD - live sourcing required at order time |  | ESP32 EN power-on delay per module datasheet Figure 9-1. | SGP40 VDDH hotplate supply decoupling.
D1 | 1 | SMBJ5.0A-13-F | Diodes Inc. unidirectional TVS clamp on fused VBUS | Diode_SMD:D_SMB | SMB / DO-214AA | Diodes Incorporated | SMBJ5.0A-13-F | LCSC C110528 | 0.1019 | LCSC catalog snapshot 2026-09-05 (see hardware/component-selection.md) |  | Unidirectional TVS: pin 1 cathode to VBUS_FUSED, pin 2 anode to GND.
D2 | 1 | GREEN STATUS | Green status LED (blink patterns, not color-only state) | LED_SMD:LED_0603_1608Metric | 0603 green LED | Lite-On | LTST-C190KGKT | TBD - no validated source | TBD | TBD - live sourcing required at order time |  | Active-low status LED. Firmware must use documented blink patterns so state is not conveyed by color alone.
F1 | 1 | 0.50A hold / 1.00A trip | Resettable fuse, USB input protection | Fuse:Fuse_1812_4532Metric | 1812 (4532 metric) | Bourns | MF-MSMF050-2 | LCSC C17313 | 0.0690 | LCSC catalog snapshot 2026-09-05 (see hardware/component-selection.md) |  | Resettable input fault protection; not a precision USB current limiter.
J1 | 1 | USB4105-GF-A | USB Type-C 5V sink receptacle with CC1/CC2 Rd sensing | Connector_USB:USB_C_Receptacle_GCT_USB4105-xx-A_16P_TopMnt_Horizontal | USB Type-C receptacle, right-angle top-mount hybrid SMT/THT | GCT | USB4105-GF-A | LCSC C3020560 | 1.0624 | LCSC catalog snapshot 2026-09-05 (see hardware/component-selection.md) |  | USB 2.0 5 V sink only. CC1/CC2 each use 5.1 kΩ Rd and feed ADC source-current sensing. No USB-PD.
J2 | 1 | SPS30 HARNESS | Board-side JST PH harness header for off-board SPS30 PM module | Connector_JST:JST_PH_S5B-PH-K_1x05_P2.00mm_Horizontal | JST PH 1x5 2.00 mm side-entry | JST | S5B-PH-K-S(LF)(SN) | TBD - no validated source | TBD | TBD - live sourcing required at order time |  | Board-side keyed harness header: 1=PM_5V, 2=RX, 3=TX, 4=SEL/floating, 5=GND. Verify assembled cable continuity.
J3 | 1 | DEBUG / PROGRAM 3V3 | 6-pin 3.3V debug/program header (EN, BOOT, U0TXD/RXD) | Connector_PinHeader_2.54mm:PinHeader_1x06_P2.54mm_Vertical | 1x6 2.54 mm header | Samtec | TSW-106-07-G-S | TBD - no validated source | TBD | TBD - live sourcing required at order time |  | 3.3 V only: pin 1=3V3, 2=GND, 3=EN, 4=BOOT/GPIO9, 5=U0TXD, 6=U0RXD.
L1 | 1 | 2.2uH 1.3A | Buck power inductor (TPS62162 recommended value) | Inductor_SMD:L_1008_2520Metric | 2.5 x 2.0 mm SMD | TDK | VLS252012T-2R2M1R3 | TBD - no validated source | TBD | TBD - live sourcing required at order time |  | TPS6216x recommended inductor; 1.3 A current rating, verify saturation margin in layout/bench review.
R1,R2 | 2 | 5.1k 1% |  | Resistor_SMD:R_0603_1608Metric | 0603 (1608 metric) | Yageo | RC0603FR-075K1L | TBD - no validated source | TBD | TBD - live sourcing required at order time |  | USB-C CC1 Rd; also forms CC1 ADC sense voltage. | USB-C CC2 Rd; also forms CC2 ADC sense voltage.
R3 | 1 | 100k 1% |  | Resistor_SMD:R_0603_1608Metric | 0603 (1608 metric) | Yageo | RC0603FR-07100KL | TBD - no validated source | TBD | TBD - live sourcing required at order time |  | TPS62162 open-drain PG pull-up.
R4,R8,R10 | 3 | 10k 1% |  | Resistor_SMD:R_0603_1608Metric | 0603 (1608 metric) | Yageo | RC0603FR-0710KL | TBD - no validated source | TBD | TBD - live sourcing required at order time |  | ESP32 EN pull-up; EN must not float. | User-button pull-up to 3.3 V. | GPIO9 boot-strap pull-up; debug header may pull low for download mode.
R5,R6 | 2 | 4.7k 1% |  | Resistor_SMD:R_0603_1608Metric | 0603 (1608 metric) | Yageo | RC0603FR-074K7L | TBD - no validated source | TBD | TBD - live sourcing required at order time |  | Single board-owned I2C SDA pull-up to 3.3 V. | Single board-owned I2C SCL pull-up to 3.3 V.
R7 | 1 | 10R 1% |  | Resistor_SMD:R_0603_1608Metric | 0603 (1608 metric) | Yageo | RC0603FR-0710RL | TBD - no validated source | TBD | TBD - live sourcing required at order time |  | SGP40 VDD RC decoupling series element per Figure 5.
R9 | 1 | 1k 1% |  | Resistor_SMD:R_0603_1608Metric | 0603 (1608 metric) | Yageo | RC0603FR-071KL | TBD - no validated source | TBD | TBD - live sourcing required at order time |  | Status LED current limit; approximately 1–2 mA at 3.3 V.
R11,R12 | 2 | 0R 1% |  | Resistor_SMD:R_0603_1608Metric | 0603 (1608 metric) | Yageo | RC0603FR-070RL | TBD - no validated source | TBD | TBD - live sourcing required at order time |  | USB D- configuration link; 0 Ω follows Espressif Figure 9-1 and permits later SI tuning. | USB D+ configuration link; 0 Ω follows Espressif Figure 9-1 and permits later SI tuning.
SW1 | 1 | SETUP / EVENT / RESET | Tactile button for event marking, setup hold, reset hold | Button_Switch_SMD:SW_SPST_PTS810 | SMD tactile switch | C&K | PTS810SJM250SMTRLFS | TBD - no validated source | TBD | TBD - live sourcing required at order time |  | Active-low local button. Firmware distinguishes event, setup hold, and factory-reset hold with explicit confirmation.
U1 | 1 | ESP32-C3-WROOM-02-N4 | Espressif ESP32-C3 Wi-Fi + native-USB MCU module | RF_Module:ESP32-C3-WROOM-02 | ESP32-C3-WROOM-02 module, 18.0 x 20.0 x 3.2 mm | Espressif Systems | ESP32-C3-WROOM-02-N4 | LCSC C2934560 | 3.2912 | LCSC catalog snapshot 2026-09-05 (see hardware/component-selection.md) |  | Native USB on pins 13/14; CC ADC sensing on GPIO0/1; antenna keepout required; GPIO2/8/9 strapping reviewed.
U2 | 1 | SPS30 | Sensirion SPS30 particulate matter sensor (off-board, UART) |  | Module with JST ZHR-5 mating connector | Sensirion AG | SPS30 | TBD - no validated source | TBD | TBD - live sourcing required at order time |  | Off-board PM module. UART selected by leaving SEL floating; housing is internally tied to signal GND.
U3 | 1 | SGP40-D-R4 | Sensirion SGP40 VOC index sensor (I2C 0x59) | bench-breathe:Sensirion_DFN-6-1EP_2.44x2.44mm_P0.8mm | DFN-6, 2.44 x 2.44 x 0.85 mm, center pad | Sensirion AG | SGP40-D-R4 | LCSC C2874215 | 6.8654 | LCSC catalog snapshot 2026-09-05 (see hardware/component-selection.md) |  | I2C 0x59. VDD uses 10 Ω/100 nF RC, VDDH uses 1 µF; EP and pin 4 to GND; no board wash.
U4 | 1 | SHT40-AD1B-R2 | Sensirion SHT40 temperature/humidity sensor (I2C 0x44) | Sensor_Humidity:Sensirion_DFN-4_1.5x1.5mm_P0.8mm_SHT4x_NoCentralPad | DFN-4, 1.5 x 1.5 x 0.5 mm, open cavity, no center land | Sensirion AG | SHT40-AD1B-R2 | LCSC C2909890 | 2.0288 | LCSC catalog snapshot 2026-09-05 (see hardware/component-selection.md) |  | I2C 0x44. Open-cavity sensor requires airflow, no copper under cavity, and separation from heat.
U5 | 1 | TPS62162DSGR | TI fixed 3.3V 1A synchronous buck regulator | Package_SON:WSON-8-1EP_2x2mm_P0.5mm_EP0.9x1.6mm_ThermalVias | WSON-8 exposed pad (DSG), 2.0 x 2.0 mm | Texas Instruments | TPS62162DSGR | LCSC C40256 | 0.9697 | LCSC catalog snapshot 2026-09-05 (see hardware/component-selection.md) |  | Fixed 3.3 V buck: FB and EP to AGND; 2.2 µH/22 µF output; tight switch loop required.
U6 | 1 | TPD4E05U06DQAR | TI 4-channel low-capacitance USB/CC ESD protection | Package_SON:USON-10_2.5x1.0mm_P0.5mm | USON-10 (DQA), 2.5 x 1.0 mm | Texas Instruments | TPD4E05U06DQAR | LCSC C138714 | 0.0819 | LCSC catalog snapshot 2026-09-05 (see hardware/component-selection.md) |  | Four low-capacitance ESD channels on USB D+/D-/CC1/CC2; place at J1 with short GND return.
U7 | 1 | TPS22919DCKR | TI load switch for gated SPS30 5V rail | Package_TO_SOT_SMD:SOT-363_SC-70-6 | SC-70-6 (DCK), 2.1 x 2.0 mm | Texas Instruments | TPS22919DCKR | LCSC C2149796 | 0.1378 | LCSC catalog snapshot 2026-09-05 (see hardware/component-selection.md) |  | Active-high PM rail switch. Internal ON pulldown defaults SPS30 off; QOD tied to output for discharge.

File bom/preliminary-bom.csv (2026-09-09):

Item | Category | Candidate_Part_or_Module | Quantity | Function | Package_or_Module | Estimated_Unit_Cost_USD | Manufacturer | MPN | Source_URL | Planning_Status | Schematic_Refs | Reconciliation | Notes
BB-001 | Controller | ESP32-C3-WROOM-02-N4 | 1 | Main MCU + Wi-Fi + native USB | 18.0x20.0mm module | 3.2912 LCSC snapshot 2026-09-05 | Espressif Systems | ESP32-C3-WROOM-02-N4 | https://documentation.espressif.com/esp32-c3-wroom-02_datasheet_en.pdf | SELECTED_M2 | U1 | MATCHED_IN_SCHEMATIC | Electrical implementation and antenna keepout owned by issue #3
BB-002 | PM Sensor | SPS30 | 1 | Particulate trend sensing | Module + JST ZHR-5 cable | TBD - authorized manufacturer source required | Sensirion AG | SPS30 | https://sensirion.com/media/documents/8600FF88/64A3B8D6/Sensirion_PM_Sensors_Datasheet_SPS30.pdf | SELECTED_M2 | U2 + J2 | MATCHED_IN_SCHEMATIC | Mating cable tracked as non-schematic item NS-002; public LCSC result lacked manufacturer identity so no LCSC property was written
BB-003 | VOC Sensor | SGP40-D-R4 | 1 | VOC proxy/index sensing | DFN-6 EP 2.44x2.44mm | 6.8654 LCSC snapshot 2026-09-05 | Sensirion AG | SGP40-D-R4 | https://sensirion.com/media/documents/296373BB/6203C5DF/Sensirion_Gas_Sensors_Datasheet_SGP40.pdf | SELECTED_M2 | U3 | MATCHED_IN_SCHEMATIC | Requires SHT40 compensation values and Sensirion Gas Index Algorithm
BB-004 | TempHumidity Sensor | SHT40-AD1B-R2 | 1 | Temperature/humidity context | DFN-4 1.5x1.5mm open cavity no center land | 2.0288 LCSC snapshot 2026-09-05 | Sensirion AG | SHT40-AD1B-R2 | https://sensirion.com/media/documents/33FD6951/6555C40E/Sensirion_Datasheet_SHT4x.pdf | SELECTED_M2 | U4 | MATCHED_IN_SCHEMATIC | Open-cavity placement and no-copper-under-sensor rules apply
BB-005 | Regulation | TPS62162DSGR | 1 | Fixed 3.3V 1A buck | WSON-8 EP 2x2mm | 0.9697 LCSC snapshot 2026-09-05 | Texas Instruments | TPS62162DSGR | https://www.ti.com/lit/ds/symlink/tps62160.pdf | SELECTED_M2 | U5 + L1 C1 C2 R3 | MATCHED_IN_SCHEMATIC | Inductor/capacitor MPNs resolved in schematic (L1 TDK VLS252012T-2R2M1R3; C1/C2/C3 Murata; see bom/bom.csv)
BB-006A | Protection | TPD4E05U06DQAR | 1 | USB D+/D-/CC1/CC2 ESD | USON-10 2.5x1mm | 0.0819 LCSC snapshot 2026-09-05 | Texas Instruments | TPD4E05U06DQAR | https://www.ti.com/lit/ds/symlink/tpd4e05u06.pdf | SELECTED_M2 | U6 | MATCHED_IN_SCHEMATIC | Place at USB connector with short ground return; C138714 is exact TI match
BB-006B | Power switch | TPS22919DCKR | 1 | Gate SPS30 5V rail | SC-70-6 | 0.1378 LCSC snapshot 2026-09-05 | Texas Instruments | TPS22919DCKR | https://www.ti.com/lit/ds/symlink/tps22919.pdf | SELECTED_M2 | U7 | MATCHED_IN_SCHEMATIC | Supports source-state recovery/suspend modes but firmware policy remains required
BB-006C | Protection | MF-MSMF050-2 | 1 | USB input resettable fault protection | 1812 | 0.0690 LCSC snapshot 2026-09-05 | Bourns | MF-MSMF050-2 | https://bourns.com/docs/product-datasheets/mf-msmf.pdf | SELECTED_M2 | F1 | MATCHED_IN_SCHEMATIC | Not a precision 500mA limiter
BB-006D | Protection | SMBJ5.0A-13-F | 1 | VBUS transient clamp | SMB DO-214AA | 0.1019 LCSC snapshot 2026-09-05 | Diodes Incorporated | SMBJ5.0A-13-F | https://www.diodes.com/assets/Datasheets/ds19002.pdf | SELECTED_M2 | D1 | MATCHED_IN_SCHEMATIC | Unidirectional device; cathode to VBUS and anode to GND; physical size reviewed in schematic
BB-007 | UI | Status LED(s) + tactile button | 1 set | Local user feedback and mark events | SMD mix | TBD - live sourcing required | Lite-On / C&K | LTST-C190KGKT / PTS810SJM250SMTRLFS | TBD | RESOLVED_IN_SCHEMATIC | D2 SW1 | MATCHED_IN_SCHEMATIC | LED and button parts selected with MPNs in schematic; live sourcing/pricing remains TBD
BB-008 | Connector | USB4105-GF-A | 1 | USB-C 5V sink + USB2 data | Hybrid SMT/THT | 1.0624 LCSC snapshot 2026-09-05 | GCT | USB4105-GF-A | https://media.digikey.com/pdf/Data%20Sheets/GCT%20PDFs/USB4105_Spec.pdf | SELECTED_M2 | J1 + R1 R2 | MATCHED_IN_SCHEMATIC | CC Rd 5.1k implemented (R1/R2); ADC source-current sensing per issue #3
BB-009 | PCB | Custom 2-layer PCB fabrication | 1 | Device carrier board | PCB | TBD - fabrication quote required | TBD | TBD | TBD | PLANNING_ONLY | non-schematic | MOVED_TO_NON_SCHEMATIC_ITEMS | Tracked as NS-001 in bom/non-schematic-items.csv; Gerbers and fab outputs generated at maturity (issue #5/#8)
BB-010 | Enclosure | 3D-printable or off-the-shelf vented enclosure | 1 | Mechanical protection and airflow guidance | Mechanical | TBD - live sourcing required | TBD | TBD | TBD | PLANNING_ONLY | non-schematic | MOVED_TO_NON_SCHEMATIC_ITEMS | Tracked as NS-003 in bom/non-schematic-items.csv; keep serviceable and repairable
BB-011 | Cabling | USB-C cable (data-capable) | 1 | Power and setup link | Cable | TBD - live sourcing required | TBD | TBD | TBD | PLANNING_ONLY | non-schematic | MOVED_TO_NON_SCHEMATIC_ITEMS | Tracked as NS-004 in bom/non-schematic-items.csv; include known-good cable in bring-up checklist
BB-012 | Fasteners | Standoffs/screws/nuts assortment | 1 set | Assembly and mounting | Hardware | TBD - live sourcing required | TBD | TBD | TBD | PLANNING_ONLY | non-schematic | MOVED_TO_NON_SCHEMATIC_ITEMS | Tracked as NS-005 in bom/non-schematic-items.csv; exact lengths depend on enclosure choice
BB-013 | Dev Access | USB-to-UART/debug adapter (if needed) | 1 | Bring-up and recovery accessory | Accessory | TBD - live sourcing required | TBD | TBD | TBD | PLANNING_ONLY | non-schematic | MOVED_TO_NON_SCHEMATIC_ITEMS | Tracked as NS-006 in bom/non-schematic-items.csv; native USB + J3 cover most cases
BB-014 | Power Supply | Certified USB wall adapter 5V | 1 | Safe external power source | Accessory | TBD - live sourcing required | TBD | TBD | TBD | PLANNING_ONLY | non-schematic | MOVED_TO_NON_SCHEMATIC_ITEMS | Tracked as NS-007 in bom/non-schematic-items.csv; user may already own; SELV/USB-only boundary

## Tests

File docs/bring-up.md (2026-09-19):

# Bench Breathe — Integration and Bring-Up Guide (A0)

Target revision: **A0** (`hardware/kicad/bench-breathe.kicad_pcb`, board
65 × 75 mm, 2 copper layers) with firmware `0.1.0-baseline`
(`firmware/`) and companion app contract v1 (`docs/protocol.md`).

**Evidence-class legend (used throughout — see `hardware/requirements.md` §10
and risk R-12):**

| Class | Means |
|---|---|
| static | geometry/compile/metadata checks reproducible from committed sources |
| simulation | host-executed code paths / device simulator, never a real board |
| bench | physical measurement on a named prototype revision |
| field | optional representative observation; never calibration/certification |

> **This guide is a bench procedure with pre-registered pass/fail limits. As
> of writing, NO section marked "bench" has been executed — no A0 prototype
> exists.** Completing a bench step means recording: date, board revision,
> instrument (model + calibration status), and raw reading, then filing the
> result under this issue's evidence. Static/simulation results may never be
> written into a bench cell.

## 0. Safety boundaries (read first)

- **USB 5 V SELV only.** No mains wiring or control, no relays/actuators,
  no USB-PD sourcing. Power the board only from a reputable 5 V USB supply
  or a current-limited bench supply set ≤ 5.5 V / ≤ 1 A.
- The device is an **advisory trend logger**. It does not determine whether
  air is safe; it is not a medical, emergency, or occupational instrument.
- If current draw exceeds the limits in Step 3, **unplug** — the PPTC F1 is
  a slow fault device, not a precision current limiter.
- J3 is 3.3 V logic only. Never inject 5 V into it; SPS30 5 V appears only
  on J2 pin 1 when the PM rail gate (U7) is enabled by firmware.

## 1. What you need

| Item | Ref | Notes |
|---|---|---|
| A0 board, stuffed | — | BOM: `bom/bom.csv` (26 lines / 37 refs; source of truth = schematic properties). No DNP lines on A0. |
| SPS30 PM module + harness cable | U2, J2 | Cable: JST ZHR-5 crimp → SPS30. See §2.3 for harness pinout; verify continuity before first power-up. |
| USB-C data-capable cable | NS-004 (bom/non-schematic-items.csv) | Known-good data cable required (charging-only cables hide the console). |
| 5 V USB supply or bench supply | NS-007 | ≥ 1 A recommended for headroom above the ~430 mA static worst-case budget. |
| Multimeter (+ shunt/µA meter or current probe for Step 3) | — | |
| USB-UART adapter (optional) | NS-006 | Only if you prefer the U0TXD/U0RXD console on J3 over native USB CDC. |
| Enclosure with airflow path (Step 7 only) | NS-003 | Vented; SPS30 intake unobstructed; SHT40 away from heat. |

**Fab/assembly note (static-class blocker carried from A0):** the committed
board has 15 open ratsnest stubs documented in
`hardware/pcb-notes.md` §Residuals and `hardware/kicad/reports/`.
**A0 is an evidence board for placement/DRC/geometry validation, not a fab
release.** Fabricate only after the A1 stub closure lands; until then, this
guide applies to whatever board revision is named in the bench record.
[PLACEHOLDER: assembly photo — replace with real photo of stuffed A0]

## 2. Wiring and pinouts

All tables below are extracted from the editable sources (schematic net
assignments + PCB pad nets + `firmware/src/main.cpp` / `device_hal.h`), not
re-typed from memory. If you change one source, regenerate the others.

### 2.1 J1 — USB-C receptacle (input power + native USB)

| Pin | Net | Function |
|---|---|---|
| A4/A8/A9/B4/B8/B9 | VBUS | 5 V in (internally bonded) |
| A5 / B5 | CC1_SENSE / CC2_SENSE | 5.1 kΩ Rd to GND (R1/R2); also ADC source-classify sense |
| A6/B6 + A7/B7 | USB_CONN_DP / USB_CONN_DM | through ESD array U6, then 0 Ω R12/R11 → USB_DP/USB_DM at the module |
| A1/A12/B1/B12, S1 | GND | shell/ground (pour-connected) |

### 2.2 J3 — debug/program header (1×6, 2.54 mm, 3.3 V only)

| Pin | Net | ESP32-C3 GPIO | Use |
|---|---|---|---|
| 1 | +3V3 | — | 3.3 V reference/monitor only — not a 500 mA rail tap |
| 2 | GND | — | |
| 3 | EN | EN | pulse low→high to reset; hold low + BOOT for download mode |
| 4 | BOOT_GPIO9 | GPIO9 | pull low during EN pulse → ROM bootloader (firmware recovery) |
| 5 | PM_UART_RX | GPIO20 (U0RXD) | console RX (module native USB is CDC; this is the secondary path) |
| 6 | PM_UART_TX | GPIO21 (U0TXD) | console TX |

### 2.3 J2 — SPS30 harness (JST PH 1×5, board side)

| Pin | Net | Mates to (SPS30 ZHR-5 cable) |
|---|---|---|
| 1 | PM_5V | red — 5 V, gated by U7 (off until firmware enables) |
| 2 | PM_UART_RX | white/blue — SPS30 TX (module RXD ← board) |
| 3 | PM_UART_TX | SPS30 RX |
| 4 | (SEL, floating via NC) | SPS30 SEL — floating selects UART mode |
| 5 | GND | black |

Verify harness continuity **unpowered** before mating to the SPS30: pin-to-pin
on both ends, and no short 1↔5.

### 2.4 Test points (19, one pad each)

TP1 VBUS · TP2 VBUS_FUSED · TP3 +3V3 · TP4 GND · TP5 PM_5V · TP6 REG_PG ·
TP7 EN · TP8 BOOT_GPIO9 · TP9 I2C_SDA · TP10 I2C_SCL · TP11 USB_DP ·
TP12 USB_DM · TP13 CC1_SENSE · TP14 CC2_SENSE · TP15 PM_ENABLE ·
TP16 USER_BUTTON_N · TP17 PM_UART_RX · TP18 PM_UART_TX · TP19 SGP_VDD

TP11/TP12 are on the **module side** of the 0 Ω links — lifting R11/R12
isolates the host-side pair.

### 2.5 Firmware GPIO map (from `firmware/src/main.cpp` / `device_hal.h`)

| GPIO | Net | Direction | Note |
|---|---|---|---|
| 0 / 1 | CC1_SENSE / CC2_SENSE | ADC | source classification (PWR-03) |
| 3 | REG_PG | input | buck power-good presence gate |
| 4 / 5 | I2C_SDA / I2C_SCL | I²C 100 kHz | SHT40 @0x44, SGP40 @0x59 |
| 6 | PM_ENABLE | output | U7 gate; LOW = PM rail off |
| 7 | STATUS_LED_K | output | active-low |
| 9 | BOOT_GPIO9 | strap | R10 10 kΩ pull-up |
| 10 | USER_BUTTON_N | input | active-low (R8 pull-up populated) |
| 20 / 21 | PM_UART_TX / PM_UART_RX | UART1 115200 8N1 | SPS30 (SHDLC) |

## 3. First power-up (bench) — smoke and rails

Pre-registered pass/fail. Stop at the first FAIL; troubleshooting matrix is §7.

| # | Step | Expected (pre-registered) | Class | Result |
|---|---|---|---|---|
| 3.1 | Visual: orientation of D1/D2/U5/U7/J1/J2, solder bridges, J2 unconnected | no bridge at U5 WSON-8 / U6 USON-10 | bench | ☐ |
| 3.2 | USB-C cable only to host port (or supply ≤1 A limit), meter in series | **< 100 mA** (RecoveryOnly — PM rail off, Wi-Fi off) | bench | ☐ |
| 3.3 | TP3↔TP4 | 3.30 V ±5 %, ripple not visible on DMM | bench | ☐ |
| 3.4 | TP1↔TP4 / TP2↔TP4 | both ≈ 5.0 V (within cable drop) | bench | ☐ |
| 3.5 | TP6 (REG_PG) | HIGH (≈ 3.3 V via R3 pull-up) | bench | ☐ |
| 3.6 | TP5 (PM_5V) | **≈ 0 V** (U7 gated off at boot) | bench | ☐ |
| 3.7 | TP13/TP14 (CC sense) with plain host port | ≈ 0.2–0.4 V default-USB window (firmware windows 200–380 mV; **bench must confirm window edges vs ADC accuracy** — open item in firmware README) | bench | ☐ |

## 4. Firmware flash + console (bench)

```sh
cd firmware && pio run -e esp32c3 -t upload        # or --upload-port /dev/ttyACM0
picocom -b 115200 /dev/ttyACM0                     # USB CDC console
```

Expected (pre-registered):

| Check | Pass criterion |
|---|---|
| Upload succeeds | esptool erase+write+verify OK |
| Console output | one NDJSON health line per second; `"protocol":"v0"` and `"fw":"0.1.0-baseline"` (baseline known delta — v1 `reason` field + serial commands are pending firmware adoption, tracked in `docs/protocol.md` Known deltas) |
| `mode` field | `"recovery"` before pairing/full-source state, `"full"` once source permits — PM stays off until then |
| Recovery path | hold BOOT (J3-4) low, pulse EN (J3-3): chip re-enumerates, upload works again |
| Full re-flash | `pio run -t erase` then upload; device returns to defaults |

## 5. Sensor interface checks (bench)

With the source in a state that permits full sensing (per §4 health line
`mode:"full"`, then `TP15` HIGH and `TP5` ≈ 5 V):

| # | Check | Expected | Class | Result |
|---|---|---|---|---|
| 5.1 | I²C scan (ESP32 I2CScanner or `GET` via serial once command set lands) | exactly **0x44** (SHT40) and **0x59** (SGP40) | bench | ☐ |
| 5.2 | TP19 (SGP_VDD) | ≈ 3.27 V (3.3 V minus ~10 Ω×≤3 mA drop) | bench | ☐ |
| 5.3 | SHT40 channel in health line | `temperature_c`/`humidity_pct` reach `"status":"ready"` within ~2 ticks (2 s default), plausible room values (e.g. 18–30 °C, 30–70 %RH) | bench | ☐ |
| 5.4 | SPS30 startup on PM enable | fan audible; `pm25` stays `"warming"` ≥ 30 s (datasheet spin-up), then `"ready"` with non-null value; TP17/TP18 show SHDLC traffic (0x7E-framed) on scope/analyser | bench | ☐ |
| 5.5 | SGP40 conditioning | `voc_raw` present (ticks, not index); treat first **1 h** as baseline-conditioning (datasheet) — values advisory until conditioned; this is the **calibration/baseline procedure**: run the device for ≥ 1 h in the target environment with clean-ish air before interpreting VOC trends. SHT40/SPS30 need **no** user calibration; SGP40 has no user offset — its baseline drifts with contamination and is advisory only | bench | ☐ |
| 5.6 | PM off again (recovery mode) | PM_5V falls to < 0.1 V within a tick of mode change; U7 QOD discharge visible on TP5 | bench | ☐ |

## 6. Power/performance checks (bench) — R-03 evidence

| # | Check | Pass limit (pre-registered from static budget, `hardware/component-selection.md`) | Class | Result |
|---|---|---|---|---|
| 6.1 | Average input current, full sensing steady state | ≤ **250 mA** @ 5 V (project ceiling) | bench | ☐ |
| 6.2 | Peak input current during concurrent Wi-Fi TX + SPS30 fan start | ≤ **500 mA**; waveform captured (instrument + probe named) — static estimate ≈ 430 mA, only ~72 mA headroom | bench | ☐ |
| 6.3 | SHT40 heater (if exercised) never concurrent with fan start/TX | no overlap event in capture | bench | ☐ |
| 6.4 | Brownout-loop guard: force droop (current-limited supply at 4.4 V) | repeated brownouts ≥ 3 pin device to RecoveryOnly, no flash loop | bench | ☐ |
| 6.5 | 3.3 V rail under 6.2 peak | no EN dip (TP7 ≥ 3.0 V), TP3 stays in spec | bench | ☐ |

## 7. Troubleshooting matrix

| Symptom | First checks | Likely cause class |
|---|---|---|
| No console, LED dead, 0 current | Cable (data-capable?), TP1 VBUS, TP2 after F1, D1 orientation | assembly/cable |
| VBUS present, no 3V3 (TP3=0) | TP6 REG_PG, U5 solder (WSON-8), L1, FB/EP to GND | assembly |
| 3V3 OK, no enumeration | TP11/TP12 vs TP (host side): lift R11/R12 to isolate; try J3-5/6 console | USB path / cable |
| Enumerates, health line `mode:"recovery"` forever | CC windows on TP13/14 (3.7) — check R1/R2 5.1 k, divider; try known 1.5 A adapter | source classify (bench item 3.7) |
| `pm25` stuck `"warming"`/`"fault"` | J2 harness continuity (§2.3), TP5=5 V after PM enable, fan sound, TP17/18 frames | harness first — most probable assembly defect |
| I²C scan finds neither/one sensor | TP9/10 ~3.3 V idle (R5/R6), U3/U4 solder (DFN), short list in §5.1 | assembly |
| SHT40 temp reads high | proximity to U5/U1 (heat) — static design places sensors on quiet island; re-check placement revision + enclosure airflow | design/bench |
| Boot after erase behaves oddly | config schema fallback to defaults is expected (validate_config), not corruption | firmware behavior (documented) |
| Device pairs but API 401s | stale token → Forget + re-pair; `ARM 30` needed for serial mutations | protocol (docs/protocol.md) |

## 8. Companion app bench acceptance

Real-device acceptance once the device serves HTTP (tracked open item —
firmware baseline does not; app currently runs against the dev simulator,
**simulation class**):

1. Serve `app/public/` from the device (COM-05) — open in phone browser.
2. Hold button ≥ 5 s → serial prints `PAIR <code>`; pair from app ≤ 10 min.
3. Live/history/export views show only `ready` values; null channels render
   as gaps, never zeros (contract v1 §Common shapes).
4. `window_open` event tag appears in history overlay and in both exports.
5. USB-serial fallback (§4) still works with Wi-Fi disabled.

## 9. Evidence ledger for this guide

| Gate | Status at writing | Evidence |
|---|---|---|
| ERC clean | static — **pass** (re-run 2026-09-19) | `hardware/kicad/reports/erc.json` (0 violations, KiCad 9.0.9) + `validate_schematic.py` PASS (34 pin-net maps, 61 components) |
| PCB DRC | static — **0 violations, 15 stubs documented, NOT fab release** | `reports/pcb-drc-final.json` + fresh re-verification `reports/pcb-drc-issue8-recheck.json` (2026-09-19: same 15 stubs / 1 zone-pseudo-rat; one stub cites a different F.Cu track pair — same electrical stub), `pcb-notes.md` §Residuals |
| BOM gates | static — **pass** (2026-09-19) | `bom/verify_bom.py` PASS (26 lines/37 refs, no fabricated price), `verify_component_selection.py` PASS |
| Firmware tests/build | simulation + static — **pass** (2026-09-19) | `pio test -e native` 19/19; `pio run -e esp32c3` SUCCESS |
| App contract tests | simulation — **pass** (2026-09-19) | `npm test` 13/13 (Node v22.23.1) |
| Steps 3–6, 8 | bench — **NOT PERFORMED — no prototype** | this guide, awaiting first A1/prototype |
| Field observation | field — none claimed | — |

[PLACEHOLDER: bench capture screenshots (current waveform, I²C scan, health-line console) — to be attached to the first bench record naming the prototype revision]

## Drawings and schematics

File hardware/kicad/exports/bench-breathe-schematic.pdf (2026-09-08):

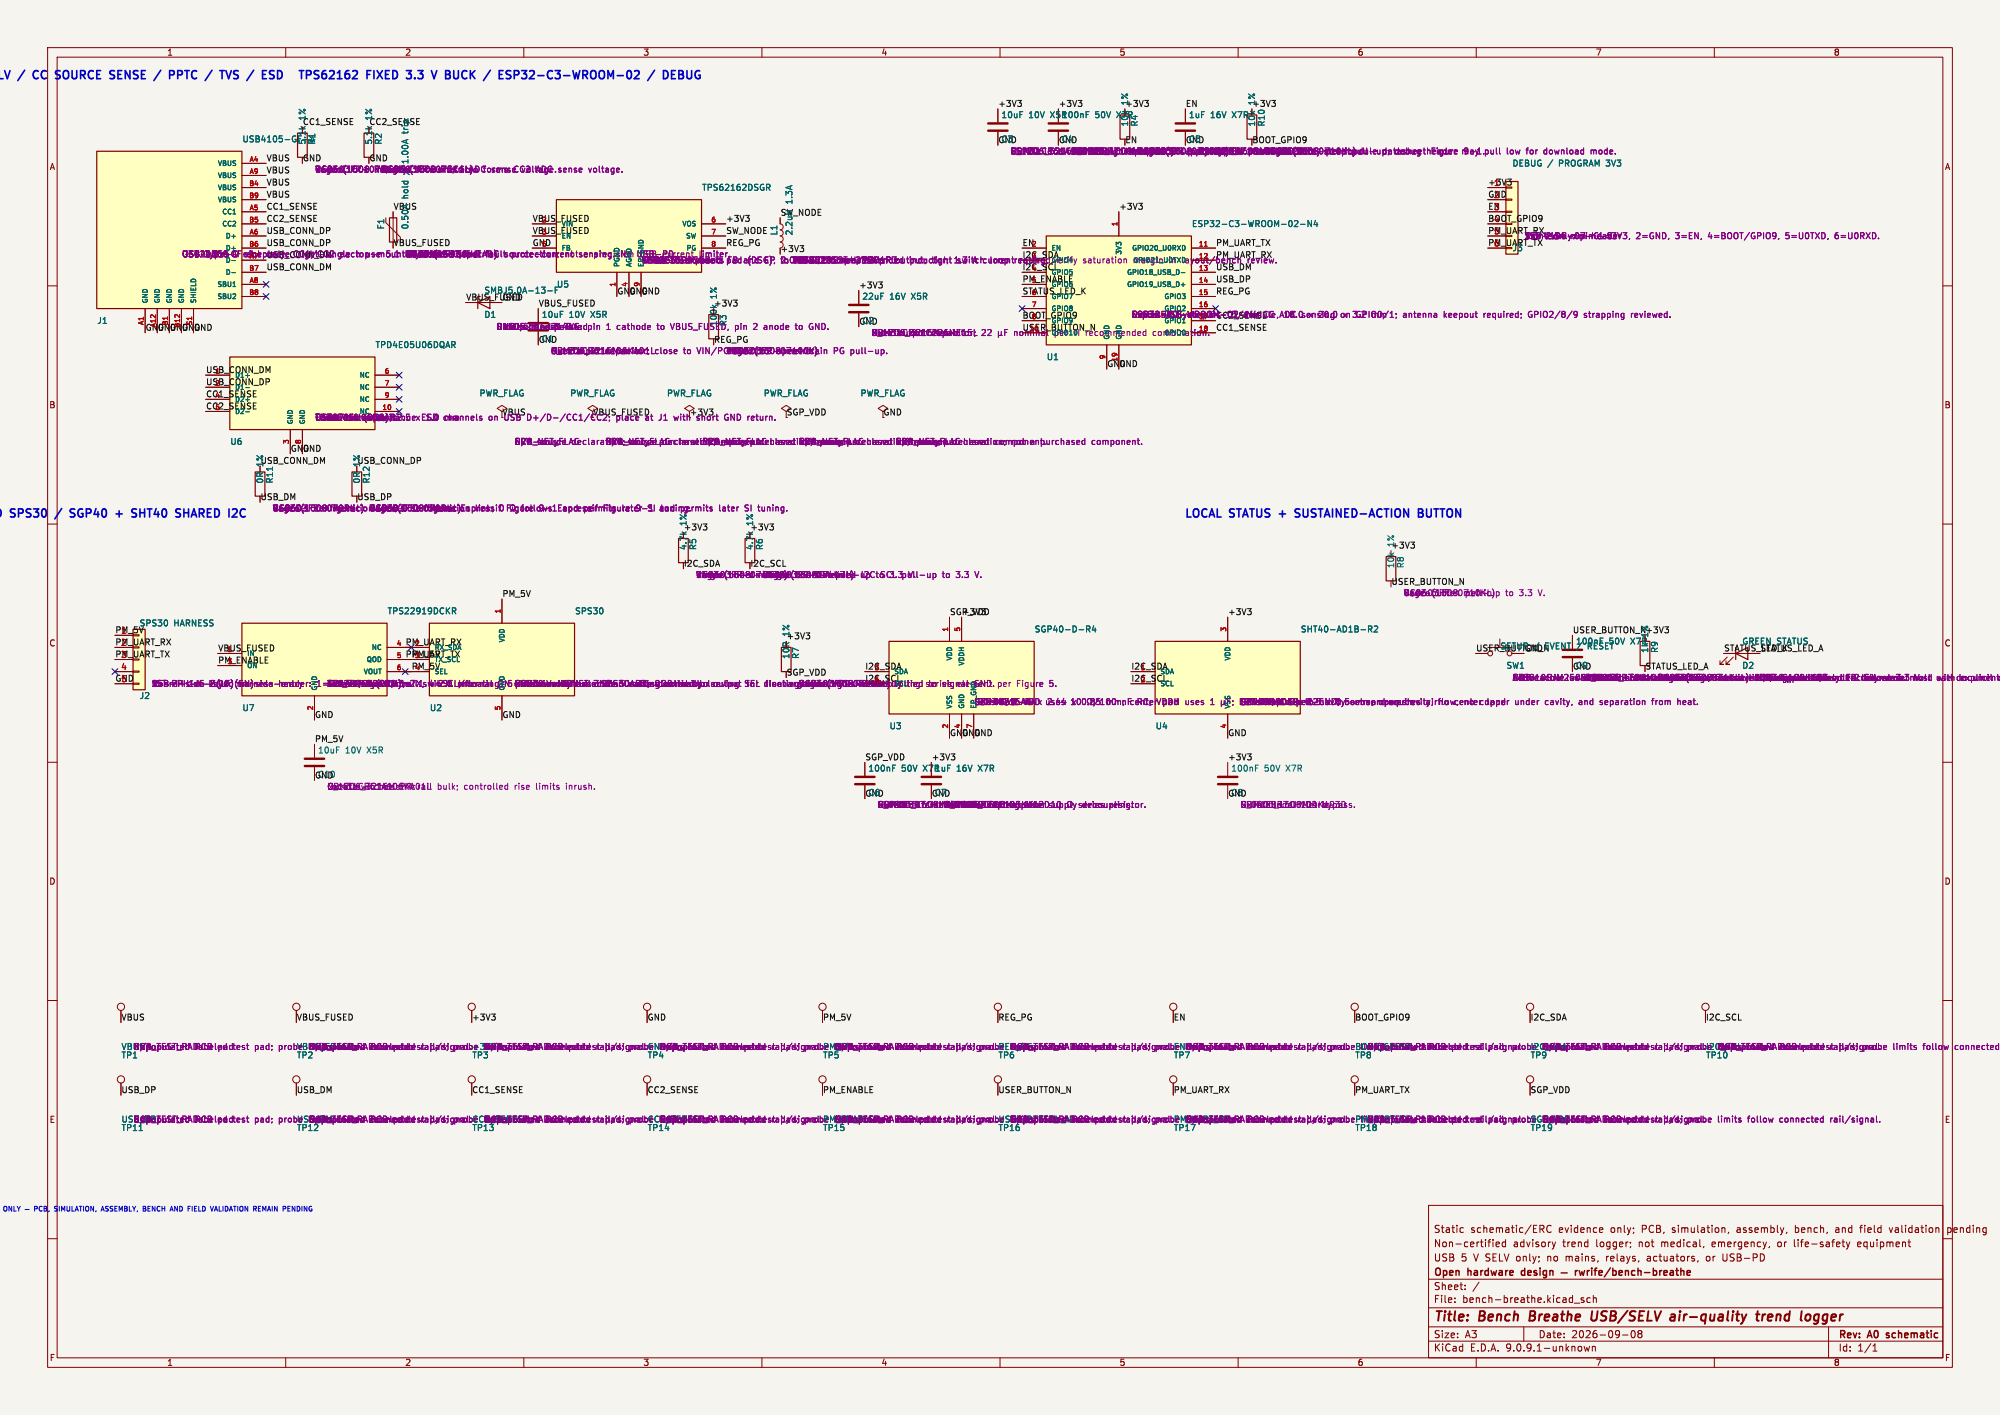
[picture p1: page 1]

RC0603FR-0710KL ESP32 Yageo 0603 (1608 EN pull-up; metric) EN must not float. 10k R10 1%

10uF 10V X5R Murata C_1206_3216Metric ESP32 GRM31CR61A106KA01L local 3.3 V bulk capacitor.

1 GND 19 GPIO20_U0RXD 11 GPIO21_U0TXD 12 GPIO18_USB_D- 13 GPIO19_USB_D+ 14 GPIO3 15 GPIO2 16 GPIO1 17 GPIO0 18 U1 ESP32-C3-WROOM-02-N4 Espressif ESP32-C3-WROOM-02 C2934560 ESP32-C3-WROOM-02-N4 Native USBSystems on pins 13/14; module, CC ADC 18.0 sensing x 20.0 xon3.2GPIO0/1; mm antenna keepout required; GPIO2/8/9 strapping reviewed. C5

1 GND 19 GPIO20_U0RXD 11 GPIO21_U0TXD 12 GPIO18_USB_D- 13 GPIO19_USB_D+ 14 GPIO3 15 GPIO2 16 GPIO1 17 GPIO0 18 C5
RC0603FR-0710KL ESP32 Yageo 0603 (1608 EN pull-up; metric) EN must not float.

4 J3DEBUG / PROGRAM 3V3 Samtec TSW-106-07-G-S 3.3 1x6 V2.54only:mmpinheader 1=3V3, 2=GND, 3=EN, 4=BOOT/GPIO9, 5=U0TXD, 6=U0RXD. 1

4 EP_GND
TexasPS62162DSGR Fixed C40256 WSON-83.3Instruments exposed V buck: pad FB and (DSG), EP 2.0to AGND; x 2.0 2.2mm þÿµH/22þÿµFoutput; tight switch loop required. PWR_FLAG

8 NC 6 NC 7 NC 9 NC 10 U6 TPD4E05U06DQAR

3 VSS U4 4 SHT40-AD1B-R2 C2909890 Sensirion SHT40-AD1B-R2 DFN-4, I2C 0x44.1.5AGOpen-cavity x 1.5 x 0.5sensor mm, open requirescavity,airflow, no center no copper land under cavity, and separation from heat. 10k R8 1%

2 NC 4 QOD 5 VOUT 6 TP3 +3V3PCB_TEST_PAD N/A Unpopulated labeled PCB padtest pad; probe limits follow connected rail/signal. TP2 VBUS_FUSED PCB_TEST_PAD N/A Unpopulated labeled PCB padtest pad; probe limits follow connected rail/signal. TP12 USB_DM PCB_TEST_PAD N/A Unpopulated labeled PCB padtest pad; probe limits follow connected rail/signal. TP13 CC1_SENSE PCB_TEST_PAD N/A Unpopulated labeled PCB padtest pad; probe limits follow connected rail/signal. TP1 VBUSPCB_TEST_PAD N/A Unpopulated labeled PCB padtest pad; probe limits follow connected rail/signal. TP11 USB_DP PCB_TEST_PAD N/A Unpopulated labeled PCB padtest pad; probe limits follow connected rail/signal. U2 SPS30 Module Sensirion SPS30 Off-board withAGPMJSTmodule. ZHR-5 UART matingselectedonnector by leaving SEL floating; housing is internally tied to signal GND. RX_SDA 2 TX_SCL 3 SEL 4 VDD
J2SPS30 HARNESS

1 GND U2 5 SPS30 Module Sensirion SPS30 Off-board withAGPMJSTmodule. ZHR-5 UART matingselectedonnector by leaving SEL floating; housing is internally tied to signal GND. C10

+3V3 GND
100nF 50V X7R Murata GRM188R71H104KA93D C_0603_1608Metric SHT40 local VDD bypass.

STATIC SCHEMATIC/ERC EVIDENCE ONLY þÿ PCB, SIMULATION, ASSEMBLY, BENCH AND FIELD VALIDATION REMAIN PENDING

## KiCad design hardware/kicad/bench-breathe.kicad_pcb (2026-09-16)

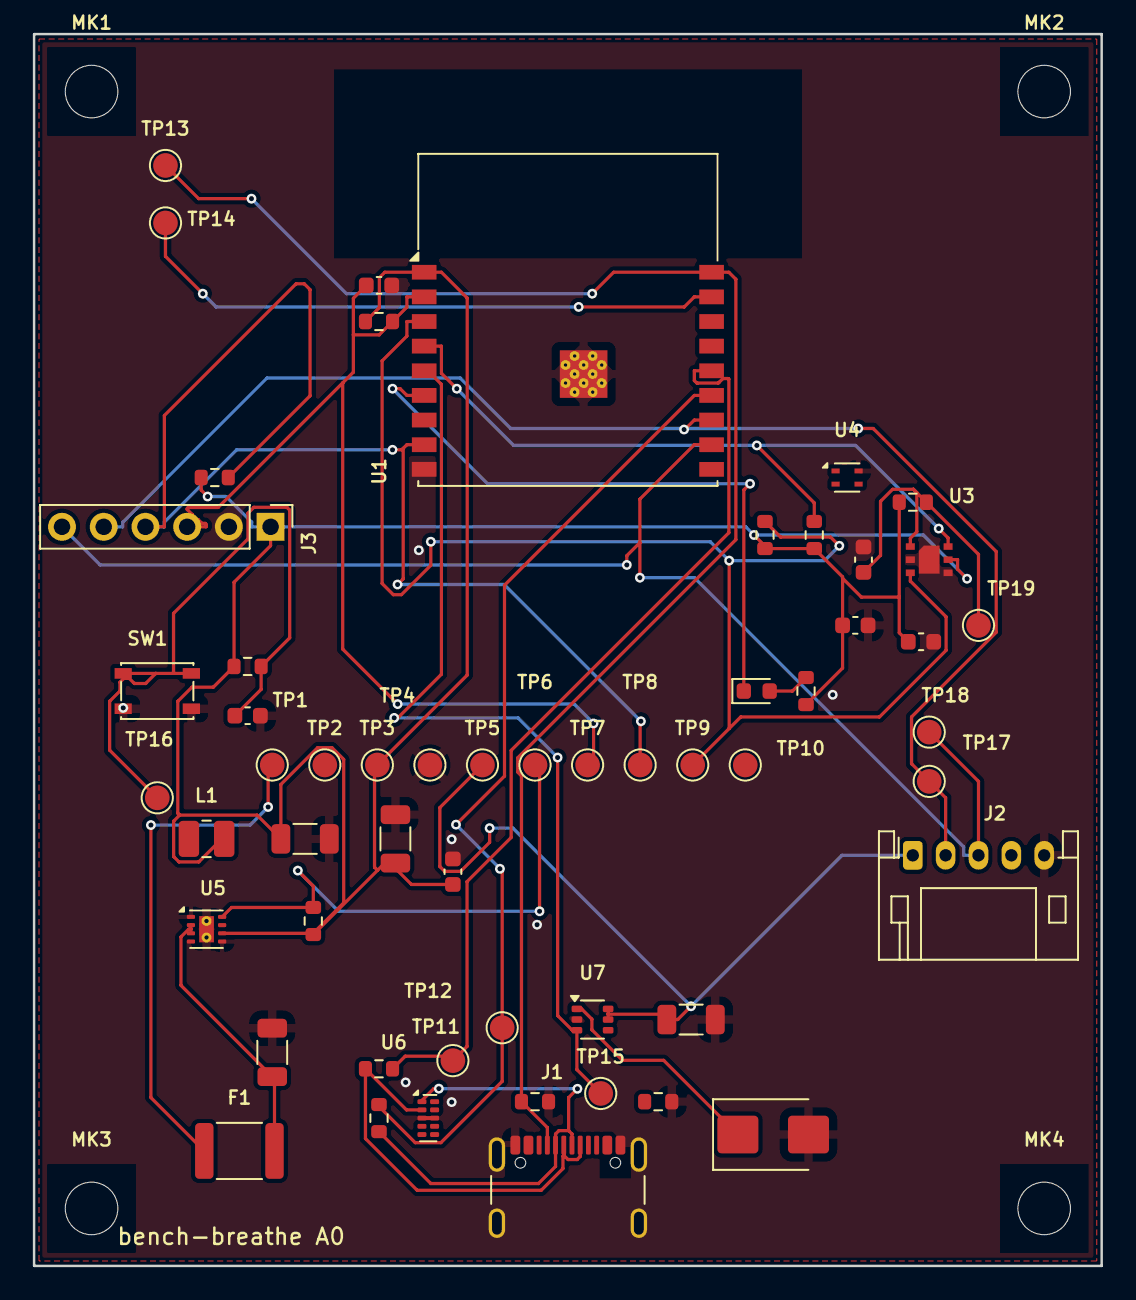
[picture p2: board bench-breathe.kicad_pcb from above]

Board: 2 copper layers, 65.0 x 75.0 mm, 59 parts (0 on the bottom side), 24 nets.

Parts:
C1, C2, C3, C10: C_1206_3216Metric
C4, C5, C6, C7, C8, C9: C_0603_1608Metric
D1: D_SMB
D2: LED_0603_1608Metric
F1: Fuse_1812_4532Metric
J1: USB_C_Receptacle_GCT_USB4105-xx-A_16P_TopMnt_Hori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; USB_C_Receptacle_GCT_USB4105-xx-A_16P_TopMnt_Horizontal
J2: JST_PH_S5B-PH-K_1x05_P2.00mm_Horizontal
J3: PinHeader_1x06_P2.54mm_Vertical
L1: L_1008_2520Metric
MK1, MK2, MK3, MK4: MountingHole_3.2mm_M3
R1, R2, R3, R4, R5, R6, R7, R8, R9, R10, R11, R12: R_0603_1608Metric
SW1: SW_SPST_PTS810
TP1, TP2, TP3, TP4, TP5, TP6, TP7, TP8, TP9, TP10, TP11, TP12, TP13, TP14, TP15, TP16, TP17, TP18, TP19: TestPoint_Pad_D1.5mm
U1: ESP32-C3-WROOM-02
U3: Sensirion_DFN-6-1EP_2.44x2.44mm_P0.8mm
U4: Sensirion_DFN-4_1.5x1.5mm_P0.8mm_SHT4x_NoCentralP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; Sensirion_DFN-4_1.5x1.5mm_P0.8mm_SHT4x_NoCentralPad
U5: WSON-8-1EP_2x2mm_P0.5mm_EP0.9x1.6mm_ThermalVias
U6: USON-10_2.5x1.0mm_P0.5mm
U7: SOT-363_SC-70-6

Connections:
/+3V3: C2.1, C3.1, C4.1, C7.1, C8.1, J3.1, L1.2, R3.1, R4.1, R5.1, R6.1, R7.1, R8.1, R9.1, R10.1, TP3.1, U1.1, U3.5, U4.3, U5.6
/BOOT_GPIO9: J3.4, R10.2, TP8.1, U1.8
/CC1_SENSE: J1.A5, R1.1, TP13.1, U1.18, U6.4
/CC2_SENSE: J1.B5, R2.1, TP14.1, U1.17, U6.5
/EN: C5.1, J3.3, R4.2, TP7.1, U1.2
/GND: C1.2, C2.2, C3.2, C4.2, C5.2, C6.2, C7.2, C8.2, C9.2, C10.2, D1.2, J1.A1, J1.A12, J1.B1, J1.B12, J1.S1, J2.5, J3.2, R1.2, R2.2, SW1.2, TP4.1, U1.9, U1.19, U3.2, U3.4, U3.7, U4.4, U5.1, U5.4, U5.5, U5.9, U6.3, U6.8, U7.2
/I2C_SCL: R6.2, TP10.1, U1.4, U3.6, U4.2
/I2C_SDA: R5.2, TP9.1, U1.3, U3.3, U4.1
/PM_5V: C10.1, J2.1, TP5.1, U7.5, U7.6
/PM_ENABLE: TP15.1, U1.5, U7.3
/PM_UART_RX: J2.2, J3.5, TP17.1, U1.12
/PM_UART_TX: J2.3, J3.6, TP18.1, U1.11
/REG_PG: R3.2, TP6.1, U1.15, U5.8
/SGP_VDD: C6.1, R7.2, TP19.1, U3.1
/STATUS_LED_A: D2.2, R9.2
/STATUS_LED_K: D2.1, U1.6
/SW_NODE: L1.1, U5.7
/USB_CONN_DM: J1.A7, J1.B7, R11.1, U6.1
/USB_CONN_DP: J1.A6, J1.B6, R12.1, U6.2
/USB_DM: R11.2, TP12.1, U1.13
/USB_DP: R12.2, TP11.1, U1.14
/USER_BUTTON_N: C9.1, R8.2, SW1.1, TP16.1, U1.10
/VBUS: F1.1, J1.A4, J1.A9, J1.B4, J1.B9, TP1.1
/VBUS_FUSED: C1.1, D1.1, F1.2, TP2.1, U5.2, U5.3, U7.1

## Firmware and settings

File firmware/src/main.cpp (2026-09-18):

// Bench Breathe firmware baseline — device glue only. All logic lives in
// src/core (unit-tested natively); this file wires the ESP32-C3 Arduino HAL
// to the Sampler/History/Button/power gating and streams NDJSON health lines
// over USB CDC (the serial fallback path, COM-03).
//
// OUT OF SCOPE for this baseline (tracked by issue #7 protocol finalization):
// full HTTP API, pairing/authorization (COM-07), Wi-Fi provisioning/setup
// mode UI (COM-06 flow beyond the button event), full-capacity flash history
// (mmap partition), and OTA/update flow. See firmware/README.md.
#include <Arduino.h>

#include "core/button.h"
#include "core/config.h"
#include "core/events.h"
#include "core/health_line.h"
#include "core/history.h"
#include "core/power_source.h"
#include "core/sensors.h"
#include "device_hal.h"

namespace {

constexpr char kFwVersion[] = "0.1.0-baseline";

// RAM arena for the baseline build. Full DAT-01 capacity (~1.04 MB raw +
// 0.28 MB agg) requires the mmap'd flash partition and is deliberately NOT
// claimed here; this arena bounds a shorter session history until then
// (4096 raw records = ~2.3 h at the 2 s default interval; 288 published
// 5-min aggregates = 24 h, satisfying DAT-02's window but not the 30-day
// requirement — both tracked as open items for the flash-store work).
constexpr uint32_t kBaselineRawCap = 4096;
constexpr uint32_t kBaselineAggCap = 288;
bb::CompactRecord g_raw[kBaselineRawCap];
bb::AggCompact g_agg[kBaselineAggCap];

bb::device::ArduClock clock_;
bb::device::ArduI2c i2c_;
bb::device::ArduUart uart_;
bb::Sht40Driver sht_(i2c_, clock_);
bb::Sgp40Driver sgp_(i2c_, clock_);
bb::Sps30Driver sps_(uart_, clock_);
bb::Sampler sampler_(sht_, sgp_, sps_);
bb::HistoryArena arena_{g_raw, g_agg, kBaselineRawCap, kBaselineAggCap};
bb::History history_{arena_};
bb::EventLog events_;
bb::ButtonFsm button_;
bb::Config config_;
bb::UsbStatus usb_{};

uint32_t last_health_ms_ = 0;

}  // namespace

void setup() {
    pinMode(6, OUTPUT);        // PM_ENABLE (U7 ON, active-high) — default LOW: PM off
    digitalWrite(6, LOW);
    pinMode(7, OUTPUT);        // STATUS_LED_K, active-low
    digitalWrite(7, HIGH);     // LED off
    pinMode(10, INPUT_PULLUP); // USER_BUTTON_N (external R8 10k pull-up populated)
    pinMode(3, INPUT);         // REG_PG from U5

    i2c_.begin();
    uart_.begin();
    Serial.begin(115200);      // USB CDC (native USB via module USB_D+/D-)
    history_.reset_counters();
}

void loop() {
    const uint32_t now_ms = static_cast<uint32_t>(clock_.monotonic_us() / 1000ULL);

    // --- Power source classification (PWR-03 matrix) ---------------------
    const int vbus_mv = digitalRead(3) ? 5000 : 0;  // REG_PG is a presence gate, not a gauge
    const int cc1_mv = analogReadMilliVolts(0);     // CC1_SENSE divider node
    const int cc2_mv = analogReadMilliVolts(1);     // CC2_SENSE divider node
    usb_.configured = static_cast<bool>(Serial);  // CDC DTR asserted by host
    const bb::SourceState src = bb::classify_source(vbus_mv, cc1_mv, cc2_mv);
    const bb::DeviceMode mode = bb::decide_mode(src, usb_);
    digitalWrite(6, bb::pm_allowed(mode) ? HIGH : LOW);

    // --- Button (COM-06 / DAT-06 detection; actions wired in issue #7) ----
    switch (button_.update(digitalRead(10) == LOW, now_ms)) {
        case bb::ButtonAction::ShortPress:
            events_.add(clock_.monotonic_us(), 0, "short_press", 11);
            break;
        case bb::ButtonAction::SetupHold:
            events_.add(clock_.monotonic_us(), 0, "setup_hold", 10);
            break;
        case bb::ButtonAction::FactoryHold:
            events_.add(clock_.monotonic_us(), 0, "factory_hold", 12);
            history_.clear_history();
            events_.clear();
            break;
        default: break;
    }

    // --- Acquisition tick (SNS-02 bounded interval) -----------------------
    static uint32_t last_tick_ms = 0;
    const uint32_t interval = bb::validate_config(config_) == bb::ConfigError::Ok
                                  ? config_.interval_ms
                                  : bb::kDefaultIntervalMs;
    if (now_ms - last_tick_ms >= interval) {
        last_tick_ms = now_ms;
        bb::RawRecord rec{};
        sampler_.tick(now_ms, bb::pm_allowed(mode), rec);
        rec.mono_us = clock_.monotonic_us();
        rec.clock_q = bb::ClockQuality::Unset;  // wall time source lands with #7
        rec.wall_us = 0;
        history_.append(rec);
    }

    // --- Serial health stream (COM-03 fallback; 1 Hz) ---------------------
    if (now_ms - last_health_ms_ >= 1000) {
        last_health_ms_ = now_ms;
        bb::CompactRecord newest{};
        const bool have_newest = history_.newest(newest);
        bb::HealthSnapshot s{};
        s.fw_version = kFwVersion;
        s.uptime_s = now_ms / 1000U;
        s.mode = mode;
        s.source = src;
        s.raw_used = history_.raw_used();
        s.raw_capacity = history_.raw_capacity();
        s.agg_used = history_.agg_used();
        s.agg_capacity = history_.agg_capacity();
        s.oldest_seq = have_newest ? (newest.seq + 1U - history_.raw_used()) : 0;
        s.newest_seq = have_newest ? newest.seq : 0;
        s.clock_q = bb::ClockQuality::Unset;
        if (have_newest) {
            using bb::status_of_bits;
            s.pm25 = status_of_bits(newest.status, 0);
            s.voc = status_of_bits(newest.status, 1);
            s.temp = status_of_bits(newest.status, 2);
            s.rh = status_of_bits(newest.status, 3);
            s.pm25_valid = s.pm25 == bb::ChannelStatus::Ready;
            s.voc_valid = s.voc == bb::ChannelStatus::Ready;
            s.temp_valid = s.temp == bb::ChannelStatus::Ready;
            s.rh_valid = s.rh == bb::ChannelStatus::Ready;
            s.pm25_value = newest.pm25 / 100.0f;
            s.voc_raw = static_cast<float>(newest.voc);
            s.temp_value = newest.temp_c / 100.0f;
            s.rh_value = newest.rh / 100.0f;
        } else {
            s.pm25 = s.voc = s.temp = s.rh = bb::ChannelStatus::Unknown;
        }
        char line[512];
        const size_t n = bb::render_health_line(s, line, sizeof(line));
        if (n) Serial.write(line, n);
    }
}

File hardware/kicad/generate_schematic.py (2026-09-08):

#!/usr/bin/env python3
"""Generate the editable Bench Breathe first-pass schematic.

Manufacturer documents cited in hardware/component-selection.md are the
pinout/electrical ground truth. The generated KiCad schematic remains editable;
this script makes the initial capture reproducible.
"""
from __future__ import annotations

import argparse
import os
from pathlib import Path

RES_DS = "https://www.yageo.com/upload/media/product/productsearch/datasheet/rchip/PYu-RC_Group_51_RoHS_L_16.pdf"
CAP_DS = "https://www.murata.com/en-global/products/capacitor/mlcc/overview/lineup"


def find_symbol_dir(explicit: str | None) -> Path:
    for candidate in (explicit, os.environ.get("KICAD_SYMBOL_DIR"), "/usr/share/kicad/symbols"):
        if candidate and Path(candidate).is_dir():
            return Path(candidate)
    raise SystemExit("KiCad symbol libraries not found; pass --symbol-dir")


def q(value: str) -> str:
    return value.replace("\\", "\\\\").replace('"', '\\"')


def custom_symbol(name: str, ref: str, footprint: str, datasheet: str,
                  description: str, pins: list[tuple[str, str, str, str]]) -> str:
    sides = {side: [pin for pin in pins if pin[3] == side] for side in "LRTB"}
    rows = max(len(sides["L"]), len(sides["R"]), 4)
    half_h = max(7.62, (rows + 1) * 1.27)
    half_w = 15.24
    output = [
        f'  (symbol "{q(name)}" (pin_names (offset 1.016)) (in_bom yes) (on_board yes)',
        f'    (property "Reference" "{q(ref)}" (at {-half_w} {half_h + 2.54} 0) (effects (font (size 1.27 1.27)) (justify left bottom)))',
        f'    (property "Value" "{q(name)}" (at {half_w} {-half_h - 2.54} 0) (effects (font (size 1.27 1.27)) (justify right top)))',
        f'    (property "Footprint" "{q(footprint)}" (at 0 {-half_h - 5.08} 0) (effects (font (size 1.27 1.27)) hide))',
        f'    (property "Datasheet" "{q(datasheet)}" (at 0 {-half_h - 7.62} 0) (effects (font (size 1.27 1.27)) hide))',
        f'    (property "ki_description" "{q(description)}" (at 0 0 0) (effects (font (size 1.27 1.27)) hide))',
        f'    (symbol "{q(name)}_0_1" (rectangle (start {-half_w} {half_h}) (end {half_w} {-half_h}) (stroke (width 0.254) (type default)) (fill (type background))))',
        f'    (symbol "{q(name)}_1_1"',
    ]

    def pin_line(pin: tuple[str, str, str, str], index: int, count: int) -> str:
        number, pin_name, pin_type, side = pin
        if side == "L":
            x, y, angle = -half_w - 5.08, (count - 1 - 2 * index) * 1.27, 0
        elif side == "R":
            x, y, angle = half_w + 5.08, (count - 1 - 2 * index) * 1.27, 180
        elif side == "T":
            x, y, angle = (index - count // 2) * 2.54, half_h + 5.08, 270
        else:
            x, y, angle = (index - count // 2) * 2.54, -half_h - 5.08, 90
        return (
            f'      (pin {pin_type} line (at {x:.3f} {y:.3f} {angle}) (length 5.08) '
            f'(name "{q(pin_name)}" (effects (font (size 1.016 1.016)))) '
            f'(number "{q(number)}" (effects (font (size 1.016 1.016)))))'
        )

    for side in "LRTB":
        for index, pin in enumerate(sides[side]):
            output.append(pin_line(pin, index, len(sides[side])))
    output += ["    )", "  )"]
    return "\n".join(output)


def write_project_library(here: Path) -> None:
    lib = here / "lib"
    pretty = lib / "bench-breathe.pretty"
    pretty.mkdir(parents=True, exist_ok=True)
    symbols = [
        custom_symbol(
            "USB4105-GF-A", "J", "Connector_USB:USB_C_Receptacle_GCT_USB4105-xx-A_16P_TopMnt_Horizontal",
            "https://media.digikey.com/pdf/Data%20Sheets/GCT%20PDFs/USB4105_Spec.pdf",
            "GCT USB4105 USB 2.0 Type-C receptacle; USB Type-C contact identifiers",
            [("A4","VBUS","passive","R"), ("A9","VBUS","passive","R"),
             ("B4","VBUS","passive","R"), ("B9","VBUS","passive","R"),
             ("A5","CC1","bidirectional","R"), ("B5","CC2","bidirectional","R"),
             ("A6","D+","bidirectional","R"), ("B6","D+","bidirectional","R"),
             ("A7","D-","bidirectional","R"), ("B7","D-","bidirectional","R"),
             ("A8","SBU1","passive","R"), ("B8","SBU2","passive","R"),
             ("A1","GND","power_in","B"), ("A12","GND","power_in","B"),
             ("B1","GND","power_in","B"), ("B12","GND","power_in","B"),
             ("S1","SHIELD","passive","B")],
        ),
        custom_symbol(
            "ESP32-C3-WROOM-02-N4", "U", "RF_Module:ESP32-C3-WROOM-02",
            "https://documentation.espressif.com/esp32-c3-wroom-02_datasheet_en.pdf",
            "Espressif ESP32-C3-WROOM-02-N4 module; pin map from datasheet v1.7 Table 3-1",
            [("1","3V3","power_in","T"), ("2","EN","input","L"),
             ("3","GPIO4","bidirectional","L"), ("4","GPIO5","bidirectional","L"),
             ("5","GPIO6","bidirectional","L"), ("6","GPIO7","bidirectional","L"),
             ("7","GPIO8","bidirectional","L"), ("8","GPIO9","bidirectional","L"),
             ("10","GPIO10","bidirectional","L"), ("11","GPIO20_U0RXD","bidirectional","R"),
             ("12","GPIO21_U0TXD","bidirectional","R"), ("13","GPIO18_USB_D-","bidirectional","R"),
             ("14","GPIO19_USB_D+","bidirectional","R"), ("15","GPIO3","bidirectional","R"),
             ("16","GPIO2","bidirectional","R"), ("17","GPIO1","bidirectional","R"),
             ("18","GPIO0","bidirectional","R"), ("9","GND","power_in","B"),
             ("19","GND","power_in","B")],
        ),
        custom_symbol(
            "SPS30", "U", "", "https://sensirion.com/media/documents/8600FF88/64A3B8D6/Sensirion_PM_Sensors_Datasheet_SPS30.pdf",
            "Sensirion SPS30 off-board particulate module; Table 4 connector map",
            [("1","VDD","power_in","T"), ("2","RX_SDA","bidirectional","L"),
             ("3","TX_SCL","bidirectional","L"), ("4","SEL","input","L"),
             ("5","GND","power_in","B")],
        ),
        custom_symbol(
            "SGP40-D-R4", "U", "bench-breathe:Sensirion_DFN-6-1EP_2.44x2.44mm_P0.8mm",
            "https://sensirion.com/media/documents/296373BB/6203C5DF/Sensirion_Gas_Sensors_Datasheet_SGP40.pdf",
            "Sensirion SGP40 VOC sensor; Table 6 transparent-top pin map",
            [("1","VDD","power_in","T"), ("2","VSS","power_in","B"),
             ("3","SDA","bidirectional","L"), ("4","GND","power_in","B"),
             ("5","VDDH","power_in","T"), ("6","SCL","bidirectional","L"),
             ("7","EP_GND","power_in","B")],
        ),
        custom_symbol(
            "SHT40-AD1B-R2", "U", "Sensor_Humidity:Sensirion_DFN-4_1.5x1.5mm_P0.8mm_SHT4x_NoCentralPad",
            "https://sensirion.com/media/documents/33FD6951/6555C40E/Sensirion_Datasheet_SHT4x.pdf",
            "Sensirion SHT40 temperature/humidity sensor; Figure 18 pin map",
            [("1","SDA","bidirectional","L"), ("2","SCL","bidirectional","L"),
             ("3","VDD","power_in","T"), ("4","VSS","power_in","B")],
        ),
        custom_symbol(
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

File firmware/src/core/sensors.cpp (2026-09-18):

#include "core/sensors.h"

#include <cmath>

namespace bb {

bool Sht40Driver::measure(Sht40Reading& out) {
    const uint8_t cmd = sht40_cmd::MeasureHighRepNoStretch;
    if (!i2c_.write(kSht40Address, &cmd, 1)) return false;
    clk_.delay_ms(12);  // > tMEAS,h max 8.3 ms (§3.1)
    uint8_t resp[6];
    if (!i2c_.read(kSht40Address, resp, 6)) return false;
    return sht40_decode_measurement(resp, out) == Sht40Error::Ok;
}

bool Sgp40Driver::measure_raw(float rh_pct, float temp_c, uint16_t& sraw_voc) {
    uint8_t frame[8];
    const size_t len = sgp40_build_measure_frame(rh_pct, temp_c, frame);
    if (!i2c_.write(kSgp40Address, frame, len)) return false;
    clk_.delay_ms(32);  // > Table 8 max measurement duration 30 ms
    uint8_t resp[3];
    if (!i2c_.read(kSgp40Address, resp, 3)) return false;
    const int32_t raw = sgp40_decode_raw_response(resp);
    if (raw < 0) return false;
    sraw_voc = static_cast<uint16_t>(raw);
    return true;
}

void Sps30Driver::pump_rx() {
    while (uart_.available() > 0) {
        reader_.feed(uart_.read_byte());
        if (reader_.complete()) {
            if (reader_.command() == 0x03 && reader_.state() == 0x00 && reader_.checksum_ok() &&
                sps30_decode_values(reader_.data(), reader_.data_len(), values_)) {
                have_values_ = true;
            }
            reader_.reset();
            return;  // one frame per pump call is sufficient for polling
        }
    }
}

bool Sps30Driver::start_measurement() {
    uint8_t frame[8];
    const size_t len = sps30_frame_start_measurement(frame);
    uart_.write(frame, len);
    // Wait out the empty ack frame window (§5.3.1 max response 20 ms).
    clk_.delay_ms(25);
    pump_rx();
    started_ = true;
    return true;  // transport-level start; value readiness is tracked by the Sampler
}

bool Sps30Driver::poll_values(Sps30Values& out) {
    if (!started_) return false;
    have_values_ = false;
    uint8_t frame[6];
    const size_t len = sps30_frame_read_values(frame);
    uart_.write(frame, len);
    // §5.3.3 max response 20 ms; give the pump 3 x 5 ms slices.
    for (int i = 0; i < 3 && !have_values_; ++i) {
        clk_.delay_ms(5);
        pump_rx();
    }
    if (!have_values_) return false;
    out = values_;
    return true;
}

void Sampler::request_pm_start(uint64_t now_mono_ms) {
    pm_start_requested_ = true;
    pm.started_mono_ms = now_mono_ms;
    pm.has_start = false;  // becomes true once start command acknowledged path completes
}

void Sampler::tick(uint64_t now_mono_ms, bool power_allows_pm, RawRecord& out) {
    // Temperature/humidity first: feeds SGP40 humidity compensation (§3.1).
    bool ok = sht_.measure(out_th_);
    out.temp_c.valid = ok;
    out.temp_c.value = ok ? out_th_.temp_c : 0.0f;
    out.temp_c.status = ok ? ChannelStatus::Ready : ChannelStatus::Fault;
    out.temp_c.reason = ok ? NullReason::None : NullReason::SensorFault;
    out.temp_c.updated_mono_us = now_mono_ms * 1000ULL;

    out.rh.valid = ok;
    out.rh.value = ok ? out_th_.rh_pct : 0.0f;
    out.rh.status = ok ? ChannelStatus::Ready : ChannelStatus::Fault;
    out.rh.reason = ok ? NullReason::None : NullReason::SensorFault;
    out.rh.updated_mono_us = now_mono_ms * 1000ULL;

    // VOC raw proxy with compensation from fresh T/RH when available.
    uint16_t sraw = 0;
    if (sgp_.measure_raw(ok ? out_th_.rh_pct : NAN, ok ? out_th_.temp_c : NAN, sraw)) {
        voc.has_value = true;
        voc.last_raw = sraw;
        voc.last_ok_mono_ms = now_mono_ms;
        if (!voc.has_start) {
            voc.started_mono_ms = now_mono_ms;
            voc.has_start = true;
        }
    } else {
        voc.status = ChannelStatus::Fault;
    }
    if (voc.has_value) {
        const bool conditioning = (now_mono_ms - voc.started_mono_ms) < kSgp40WarmingMs;
        voc.status = conditioning ? ChannelStatus::Warming : ChannelStatus::Ready;
        out.voc.valid = true;
        out.voc.value = static_cast<float>(voc.last_raw);
        out.voc.status = voc.status;
        out.voc.reason = NullReason::None;
        out.voc.updated_mono_us = voc.last_ok_mono_ms * 1000ULL;
    } else {
        out.voc.valid = false;
        out.voc.status = voc.status;
        out.voc.reason = voc.status == ChannelStatus::Fault ? NullReason::SensorFault
                                                           : NullReason::NotYetMeasured;
        out.voc.value = 0.0f;
        out.voc.updated_mono_us = 0;
    }

    // PM channel: power-gated when the source state forbids the fan (PWR-03).
    if (!power_allows_pm) {
        pm.status = ChannelStatus::Unknown;
        out.pm25.valid = false;
        out.pm25.status = ChannelStatus::Unknown;
        out.pm25.reason = NullReason::PowerGated;
        out.pm25.value = 0.0f;
        out.pm25.updated_mono_us = 0;
        return;
    }
    if (pm_start_requested_ && !pm_started_) {
        sps_.start_measurement();
        pm_started_ = true;
        pm_start_requested_ = false;
        pm.started_mono_ms = now_mono_ms;
        pm.has_start = true;
    }
    Sps30Values v;
    if (sps_.poll_values(v)) {
        pm.has_value = true;
        pm.last_value = v.pm2_5;
        pm.last_ok_mono_ms = now_mono_ms;
    }
    if (pm.has_value) {
        const bool warming = !pm.has_start || (now_mono_ms - pm.started_mono_ms) < kSps30WarmingMs;
        pm.status = warming ? ChannelStatus::Warming : ChannelStatus::Ready;
        out.pm25.valid = true;
        out.pm25.value = pm.last_value;
        out.pm25.status = pm.status;
        out.pm25.reason = NullReason::None;
        out.pm25.updated_mono_us = pm.last_ok_mono_ms * 1000ULL;
    } else {
        // No fresh value yet (empty frame / just started): explicit null with
        // reason; if we had a prior value it would repeat with retained age.
        out.pm25.valid = false;
        out.pm25.status = pm.has_start ? ChannelStatus::Warming : ChannelStatus::Unknown;
        out.pm25.reason = NullReason::NotYetMeasured;
        out.pm25.value = 0.0f;
        out.pm25.updated_mono_us = 0;
    }
}

}  // namespace bb

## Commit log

2026-09-06 docs: scaffold bench-breathe hardware project
    [preliminary-bom.csv]
2026-09-07 hardware: select datasheet-backed components (#10)
    [bench-breathe.kicad_sch, preliminary-bom.csv]
2026-09-08 hardware: complete A0 schematic (#11)
    [bench-breathe.kicad_sch]
2026-09-09 bom: establish schematic-source BOM export workflow and commit bom/bom.csv (#12)
    - export_bom.py drives kicad-cli 'sch export bom' (ungrouped) and merges
    identical parts in-script with reference ranges; kicad-cli 9.0.9
    multi-field --group-by silently fails to collapse rows, so merging
    lives in-script (documented).
    - Supplier_Source carries LCSC codes only where the schematic has a
    manufacturer-validated LCSC property; all other rows are TBD.
    - Estimated_Unit_Cost_USD is populated only from the dated LCSC snapshot
    in hardware/component-selection.md; every other row stays TBD. No
    live-scraped or fabricated stock/price data.
    - verify_bom.py gate: byte-identical regeneration, full 37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
    [bom.csv, non-schematic-items.csv, preliminary-bom.csv]
2026-09-16 hardware: A0 PCB layout, routed DRC with documented exceptions (#13)
    Create hardware/kicad/bench-breathe.kicad_pcb via pcbnew API build
    (scripts/build_pcb.py) from the #11 schematic netlist: 65x75 mm 2-layer,
    placed by functional zone with antenna keepout, final routed state
    372 tracks / 43 vias (36 routed + 7 GND pour-stitch), filled GND pours
    both layers (F.Cu 3142 mm2, B.Cu 3701 mm2).
    kicad-cli pcb drc 9.0.9 (error+warning severities): 0 violations;
    17 unconnected_items = 2 GND-pour pseudo-ratsnest pairs + 15 open ratsnest
    edges retained as the explicit pre-fab blocker, with per-pair collision
    evidence (reports/ratsnest-diagnosis-final.txt) and named A1 fixes in
    hardware/pcb-notes.md. Th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
    [bench-breathe.kicad_pcb]
2026-09-18 firmware: baseline build, tests, power gating, and sensor pipeline (#14)
    - Portable C++ core (src/core) unit-tested natively over datasheet vectors:
    SHT4x v6.4 4.4/4.6, SGP40 v1.2 Tables 9-10, SPS30 v2.0 5.2/5.3 example frames
    - SPS30 SHDLC codec (checksum, byte-stuffing, frame reader), SHT40/SGP40
    command layer, sampler with warm-up windows and explicit-null semantics
    - USB source-state gating per requirements.md PWR-03 source-state matrix
    - Bounded history (24 B records, oldest-first rollover, 5-min aggregate
    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
2026-09-19 app: companion web app MVP and finalized v1 protocol contract (#15)
    - docs/protocol.md finalized from Draft v0 to contract v1 (COM-04):
    normative HTTP/serial wire shapes, units, limits, error-code registry,
    authorization model (COM-06/07), explicit v0->v1 breaking changes,
    compatibility rules, and known firmware deltas.
    - app/public: zero-dependency static companion app (device-served,
    same-origin only, no build step, per COM-05): setup/pairing flow,
    live view with data-quality states, trend chart, history, event
    tagging, CSV/JSON export, settings, and documented data-ownership
    and LAN threat-model behavior (COM-09).
    - app/dev/stub-server.mjs: Node-stdlib dev simulator implemen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
2026-09-19 docs: publish integration bring-up guide and release artifact checklist (#16)
    Issue #8 deliverables, all evidence-class honest (static/simulation/bench/
    field kept distinct per R-12):
    - docs/bring-up.md: assembly/bench procedure for A0 with wiring + pinout
    tables extracted from the editable KiCad sources and firmware HAL (J1/J2/
    J3, 19 test points, GPIO map), pre-registered pass/fail limits for first
    power-up, flashing/recovery, sensor interface and power (R-03) checks,
    SGP40 baseline-conditioning calibration procedure, troubleshooting
    matrix, and an evidence ledger. All bench cells are explicitly
    UNEXECUTED - no prototype exists.
    - docs/release-checklist.md: per-subsystem fabri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
